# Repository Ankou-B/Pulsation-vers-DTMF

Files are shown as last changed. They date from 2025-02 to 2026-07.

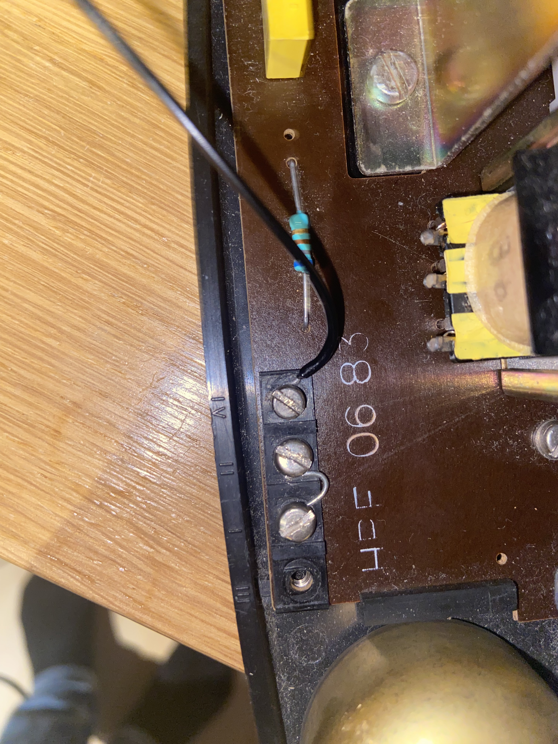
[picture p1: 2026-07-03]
Photos/Vieille photo manuelle/IMG_0554.jpg

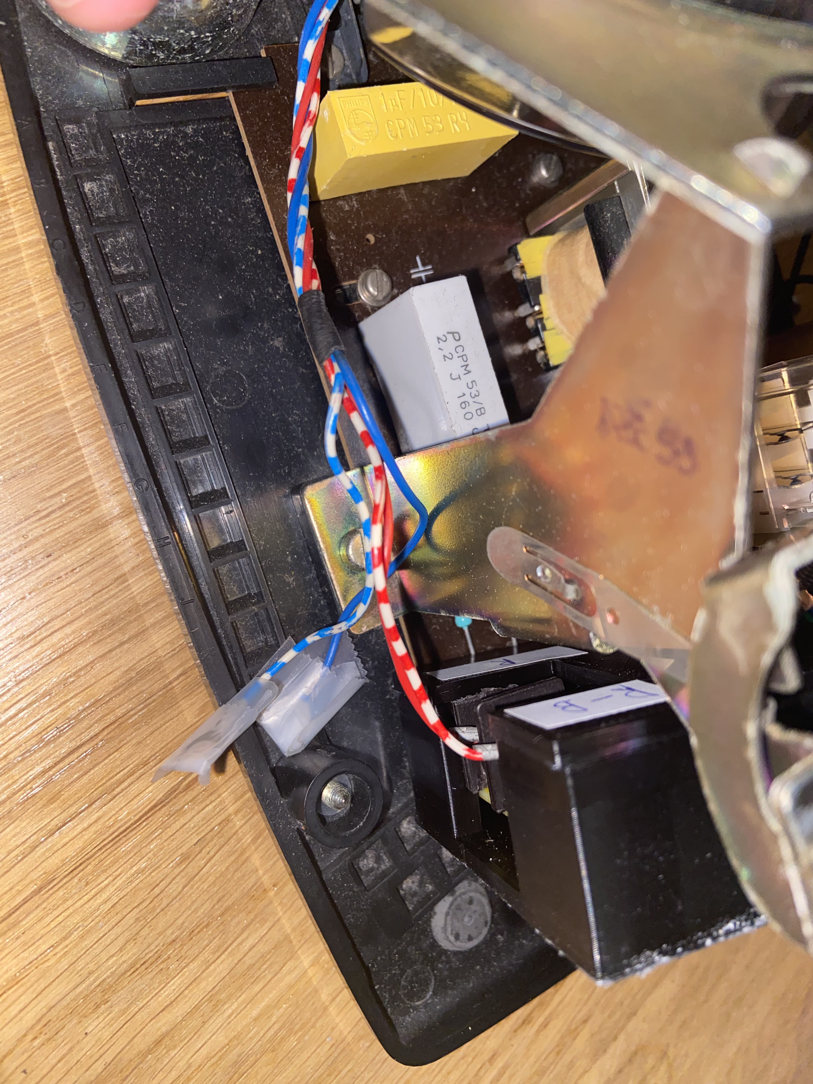
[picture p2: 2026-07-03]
Photos/Vieille photo manuelle/IMG_0558.jpg

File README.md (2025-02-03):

## 🇫🇷 Français

# Pulsation vers DTMF

Ce projet a pour but de faire revivre de vieux téléphones à cadran en leur permettant de composer des numéros à nouveau, malgré l'arrêt des lignes analogiques. 

## 🇺🇸🇬🇧 English

# Pulse to DTMF

This project aims to bring old rotary phones back to life by allowing them to dial numbers again, despite the shutdown of analog lines.

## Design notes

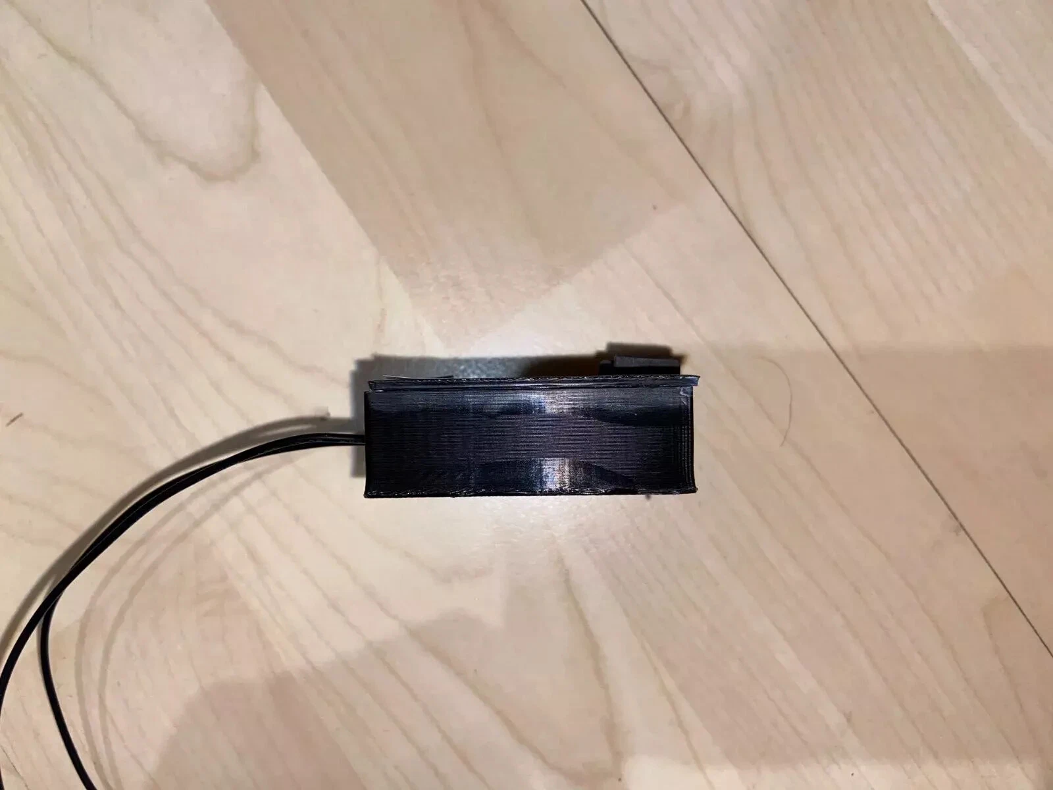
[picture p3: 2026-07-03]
Photos/Vieille photo convertisseur/3/s-l1600 (6).webp

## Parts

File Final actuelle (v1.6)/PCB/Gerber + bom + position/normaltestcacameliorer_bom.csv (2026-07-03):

Designator | Footprint | Quantity | Value | LCSC Part #
 | 7f5ab76e-00c1-41d5-9dfb-255ff1bbb225 | 1
100NF_CONDENSATEUR_CERAMIQUE_1206_1, 100NF_CONDENSATEUR_CERAMIQUE_1206_2 | 1206 | 2 | 100nf Ceramic Capacitor 1206 | C1945
10K_RESITANCE_0603_2 | 0603 | 1 | 10k resistor 0603 | C2930027
20K_RESISTANCE | 0603 | 1 | 20k 0603 | C2907124
BORNIER_A_VIS_GROS | YK3310203000G | 1 | P=8.25mm Barrier Blocks RoHS | C49023053
BORNIER_BLEU | TerminalBlock_MaiXu_MX126-5.0-02P_1x02_P5.00mm | 1 | KF301-5.0-2P | C474881
CONDENSATEUR_CHIMIQUE | C_Elec_5x5.8 | 1 | 50V10UF | C2992603
MICROCONTRÔLEUR | SOIC8-N_MC_MCH-M | 1 | PMS150C | C129127
PONT_REDRESSEUR | TO-269AA_3P8X4P75_DIO-M | 1 | MB10S | C2886577
QUARTZ | QUARTZ | 1 | 3.579545 HC-49S | C20617532
RESISTANCE_12K_0603 | 0603 | 1 | 12k resistor 0603 | C2907097
RESISTANCE_1K_0603_1, RESISTANCE_1K_0603_2 | 0603 | 2 | 1k resistor 0603 | C2907113
TP5088N | DIL-14 | 1
TRANSISTOR_NPN | SOT-23_DIO | 1 | MMBT2222A | C916372
Z5.1V | D_DO-41_SOD81_P10.16mm_Horizontal | 1 | 1N4733A 1W 5.1V D_DO-41_SOD81_P10.16mm_Horizontal | C7441079

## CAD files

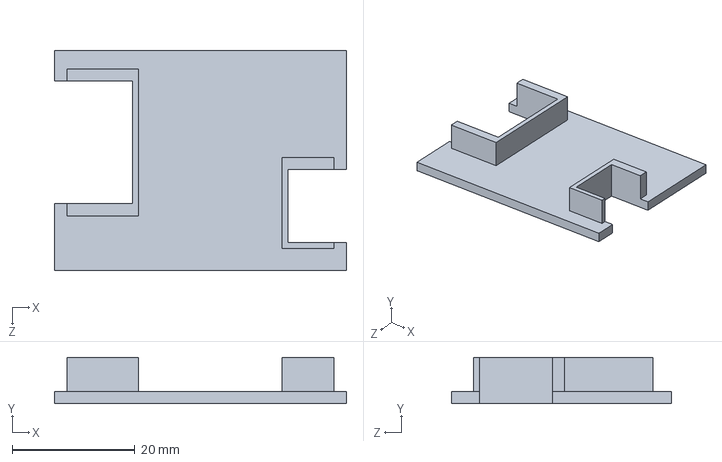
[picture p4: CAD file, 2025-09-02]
Avant le site (v1.5)/3D/Coque LiperPhone v1.5/Haut LiperPhone v1.5.SLDPRT
47.5 x 7.50 x 35.8 mm

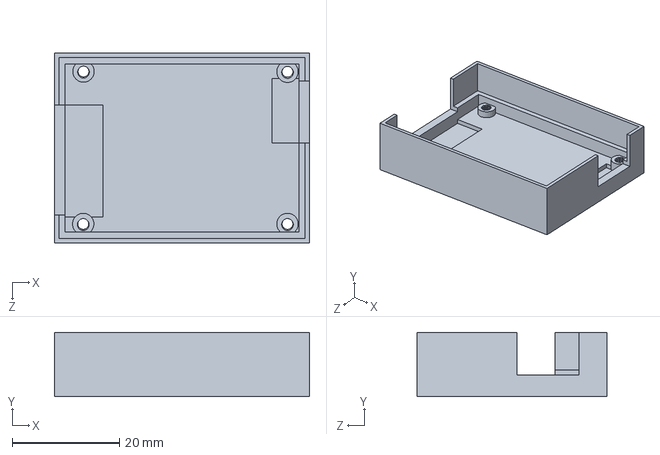
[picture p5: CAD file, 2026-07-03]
Final actuelle (v1.6)/3D/Bas LiperPhone v1.6.SLDPRT
47.5 x 12.0 x 35.3 mm

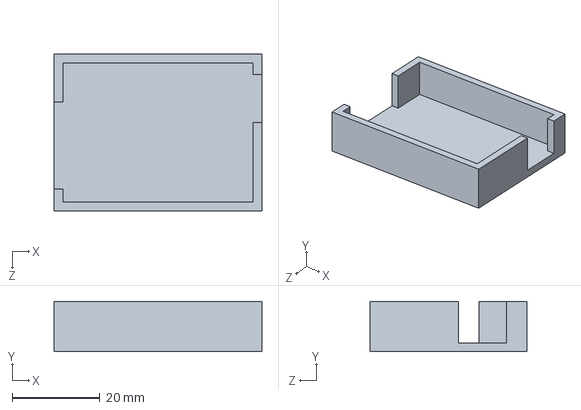
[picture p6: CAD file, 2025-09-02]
Avant le site (v1.5)/3D/Coque LiperPhone v1.5/Bas LiperPhone v1.5.SLDPRT
47.5 x 11.5 x 35.8 mm

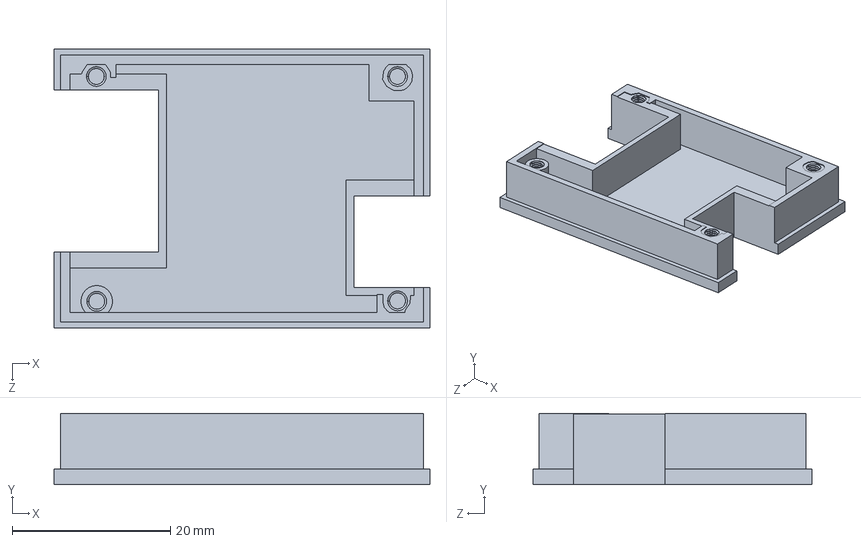
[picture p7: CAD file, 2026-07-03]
Final actuelle (v1.6)/3D/Haut LiperPhone v1.6.SLDPRT
47.5 x 9.00 x 35.3 mm

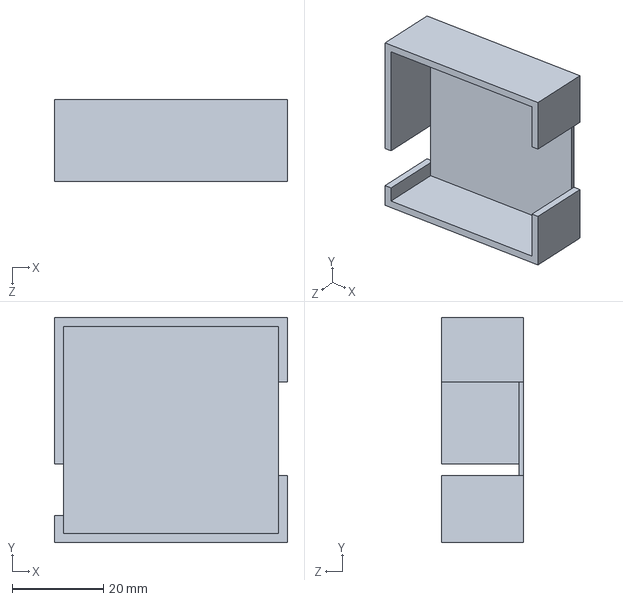
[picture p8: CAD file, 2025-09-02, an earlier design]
Ancien final (v1.2)/3D/coque LiperPhone/Aelig 1 (3).SLDPRT
51.2 x 49.5 x 18.0 mm

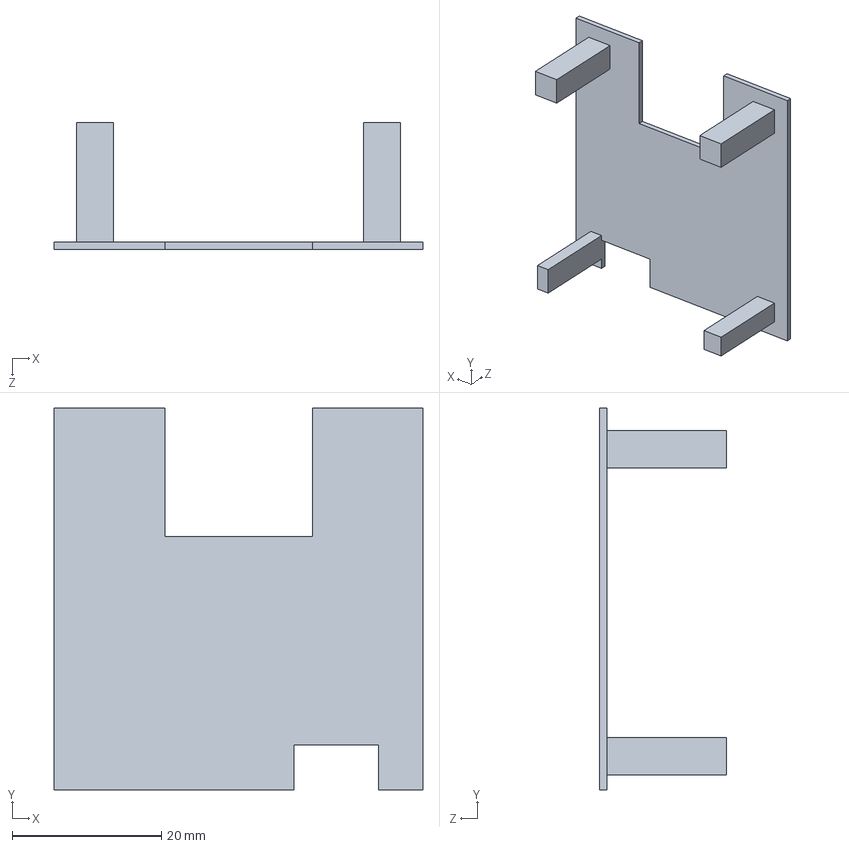
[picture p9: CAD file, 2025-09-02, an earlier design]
Ancien final (v1.2)/3D/coque LiperPhone/Aelig 2 (1).SLDPRT
49.5 x 51.2 x 17.0 mm

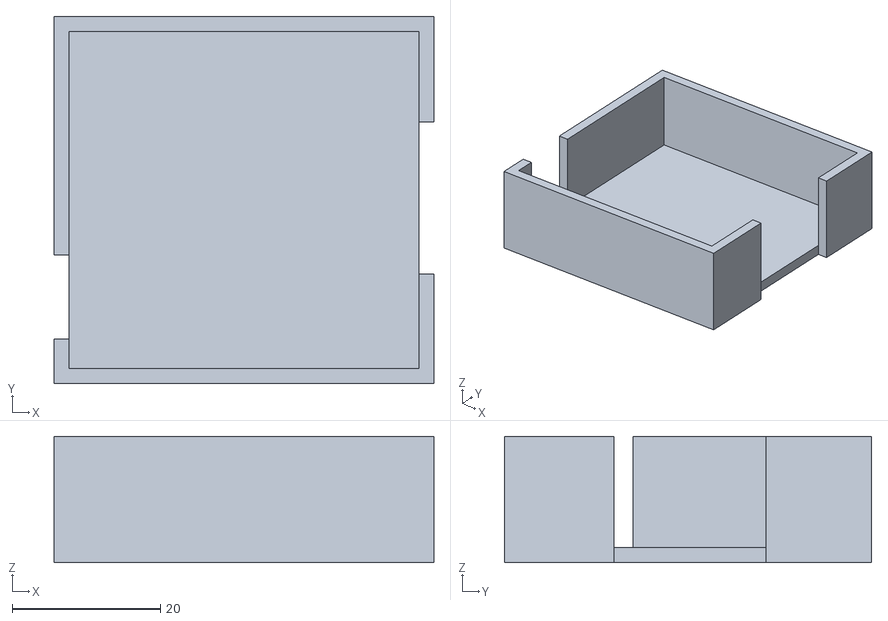
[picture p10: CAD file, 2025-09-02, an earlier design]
Ancien final (v1.2)/3D/coque LiperPhone/Liperphone bas v1.STL
51.2 x 49.5 x 17.0

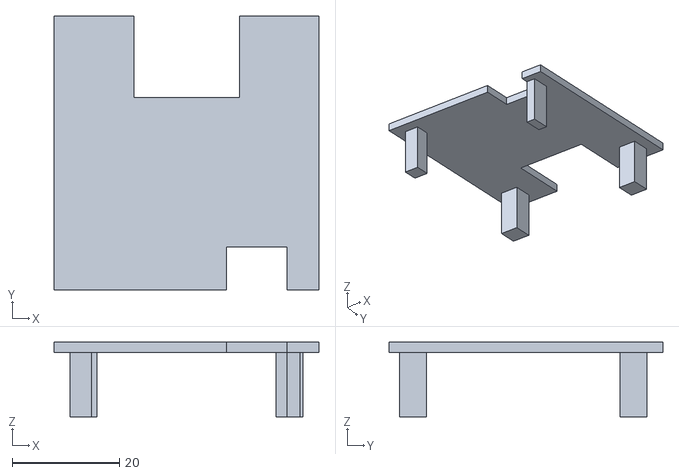
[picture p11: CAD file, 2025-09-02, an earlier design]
Ancien final (v1.2)/3D/coque LiperPhone/Liperphone haut v1.STL
49.5 x 51.2 x 14.0

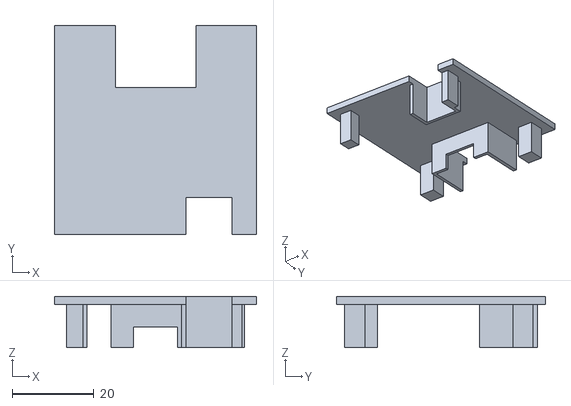
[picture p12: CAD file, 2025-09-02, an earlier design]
Ancien final (v1.2)/3D/coque LiperPhone/Liperphone haut v3.STL
49.5 x 51.2 x 12.5

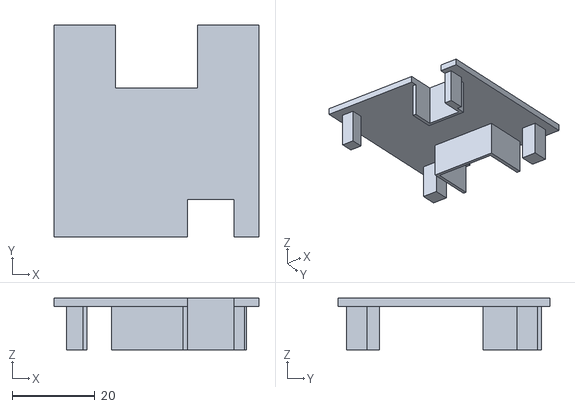
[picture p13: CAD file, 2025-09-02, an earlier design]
Ancien final (v1.2)/3D/coque LiperPhone/Liperphone haut v2.STL
49.5 x 51.2 x 12.5

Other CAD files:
Ancien final (v1.2)/3D/coque LiperPhone/Aelig 1 1mm.STL
Ancien final (v1.2)/3D/coque LiperPhone/Aelig 2 1mm.STL
Avant le site (v1.5)/3D/Coque LiperPhone v1.5/Bas LiperPhone v1.5.STL
Avant le site (v1.5)/3D/Coque LiperPhone v1.5/Haut LiperPhone v1.5.STL
Final actuelle (v1.6)/3D/Bas LiperPhone v1.6.STL
Final actuelle (v1.6)/3D/Haut LiperPhone v1.6.STL

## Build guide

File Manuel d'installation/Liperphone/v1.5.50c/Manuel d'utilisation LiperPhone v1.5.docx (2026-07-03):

Manuel d’utilisation - LiperPhone v1.5

Les instructions sont simples et peu nombreuses : la lecture de ce document sera rapide, rassurez-vous !

À éviter absolument :
Ne tournez pas le cadran trop violemment ni par à-coups. Il s’agit d’un matériel d’époque, qui devient un peu plus fragile avec le temps, et qui mérite donc d’être manipulé avec soin. Un usage brutal pourrait non seulement l’endommager, mais aussi provoquer des erreurs de numérotation avec le LiperPhone, ce que nous voulons éviter, évidemment.

Utilisation du cadran
Une fois arrivé à la butée avec le chiffre désiré, relâchez simplement le cadran et laissez-le revenir tranquillement à sa position initiale. Vous entendrez un son dans l’écouteur, signe que tout s’est bien déroulé. Il est important de ne pas accélérer ni freiner le retour du cadran : cela risquerait de provoquer une erreur de numérotation du LiperPhone.

Composer un chiffre est donc très simple : amenez le chiffre voulu jusqu’à la butée, puis relâchez immédiatement le cadran.

Important : attendez que la tonalité du chiffre en cours soit terminée (≈ ¼ de seconde) avant de commencer le chiffre suivant. Si vous enchaînez trop vite, votre box peut mal interpréter la numérotation.

Numérotation — cadence et cas particuliers

Si, lors de l’amener à la butée, la rotation est très lente ou hésitante, le convertisseur peut générer un chiffre parasite (brève tonalité entendue dans l’écouteur).
Dans ce cas :

- Raccrochez au moins 5 secondes,
- puis recommencez votre numéro depuis le début en effectuant des mouvements francs et réguliers.

Caractères spéciaux

- Pour composer un *, amenez le chiffre 1 jusqu’à la butée, attendez 2 secondes, puis relâchez le cadran. Le LiperPhone générera alors un * au lieu d’un 1.
- Pour composer une #, procédez de la même manière avec le chiffre 2.
- Pou composer le caractère d’appel internationale +, procédez de la même manière avec le chiffre 3. Information complémentaire, vous entendrez deux tonalités qui se suivent, c’est normal.

Comme vous pouvez le constater, il n’y a pas grand-chose à lire : le fonctionnement d’un téléphone à cadran reste simple et intuitif.

Dépannage rapide

- Rien ne se passe après un raccrochage/décrochage très rapide, ou une tonalité continue se déclenche : raccrochez 5 secondes, puis recommencez la numérotation depuis le début.
- Chiffre inattendu entendu pendant la rotation : cadence irrégulière → appliquez la procédure ci-dessus (raccrocher 5 s puis recommencer).

Liper

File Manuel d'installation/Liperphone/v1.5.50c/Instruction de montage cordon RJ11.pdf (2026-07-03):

Instruction d’installation cordon RJ11

Merci pour votre achat !

Si vous avez un problème avec les instructions, n’hésitez pas à m’envoyer un message sur la plateforme où vous avez acheté le produit. (Mais lisez et appliquez bien toutes les instructions avant).

Vous trouverez ci-dessous les instructions d’installation du cordon RJ11.

Pour le modèle S63

1ʳᵉ étape : Ouvrir le téléphone à cadran

Pour ouvrir le téléphone à cadran, rien de plus simple : sous celui-ci, il y a deux vis. Il suffit de les dévisser complètement toutes les deux, et la coque devrait se retirer sans forcer.

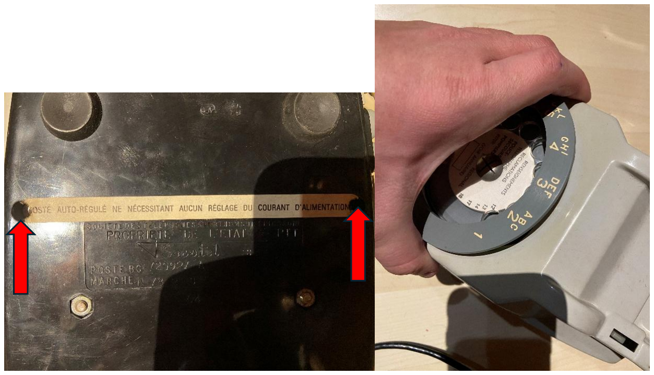
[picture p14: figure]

Un exemple vidéo si besoin :
(2:29 – 2:54) https://www.youtube.com/watch?v=tPKWj8iQFak

2ᵉ étape : Retirer les fils de l’ancienne prise

Les fils à débrancher se situent ici sur le téléphone. Dévissez tranquillement pour ne pas retirer la vis complètement.

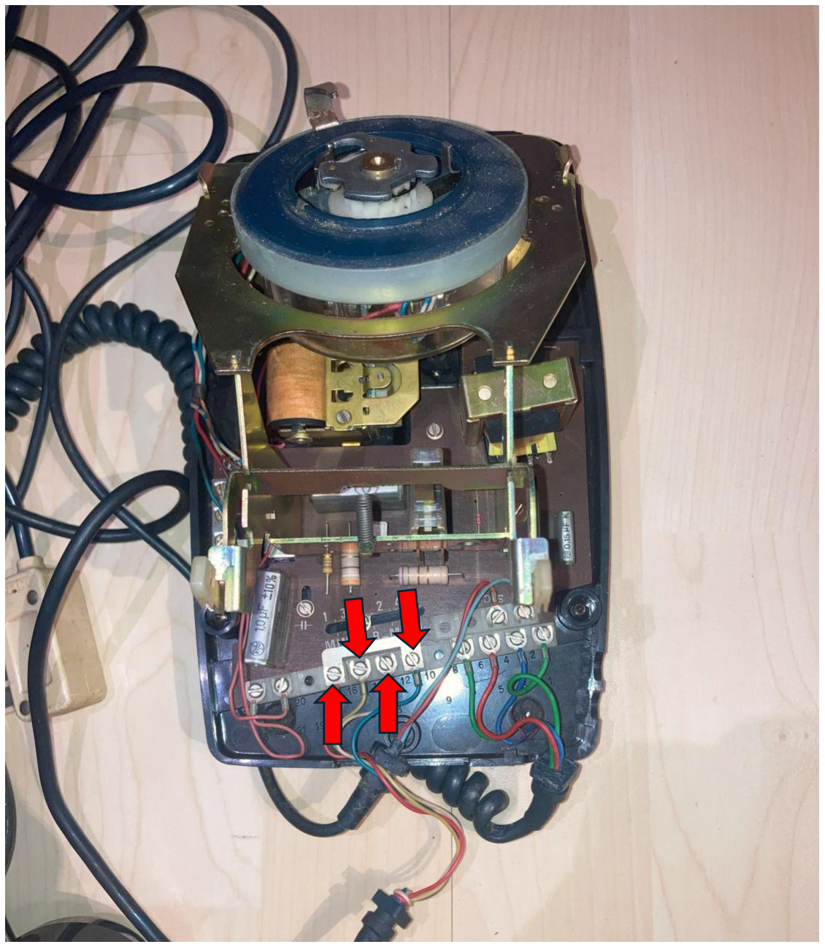
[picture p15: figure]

Il ne faut pas retirer les vis, juste déloger les câbles. Veillez à laisser le petit pont en métal bien en place.

3ᵉ étape : Visser les fils de la nouvelle prise

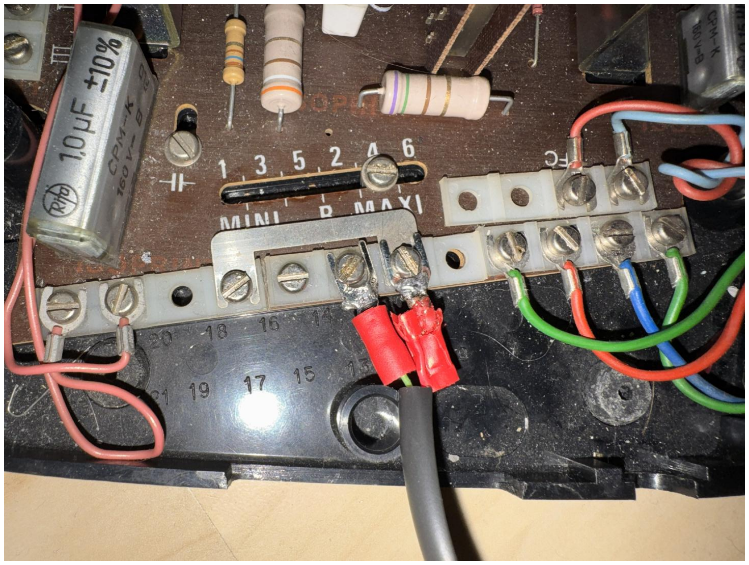
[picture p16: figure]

Le sens des fils n’a pas d’importance : les deux fils sont interchangeables et peuvent aller sur n’importe laquelle des deux bornes de la photo.
Vissez fermement pour que les cosses ne puissent pas bouger.
Revissez aussi les vis sans cosses et portez une attention particulière à celle avec le petit pont de métal : elle doit être très bien serrée pour que le contact se fasse correctement.

4ᵉ étape : Vérification

Avant de refermer, n’hésitez pas à brancher votre téléphone à votre ligne (box ADSL/fibre, prise murale, etc.) et à essayer de vous appeler. Cela vous permettra de vérifier si le signal arrive correctement au téléphone.

5ᵉ étape : Refermez, c’est terminé

Quand vous refermez, vérifiez bien qu’aucun câble ne dépasse de la coque du téléphone et revissez correctement les vis de ladite coque.
Faites en sorte que le petit embout soit installé comme ceci lors de la fermeture, quitte à devoir pousser un peu le câble à l’intérieur pour y parvenir.

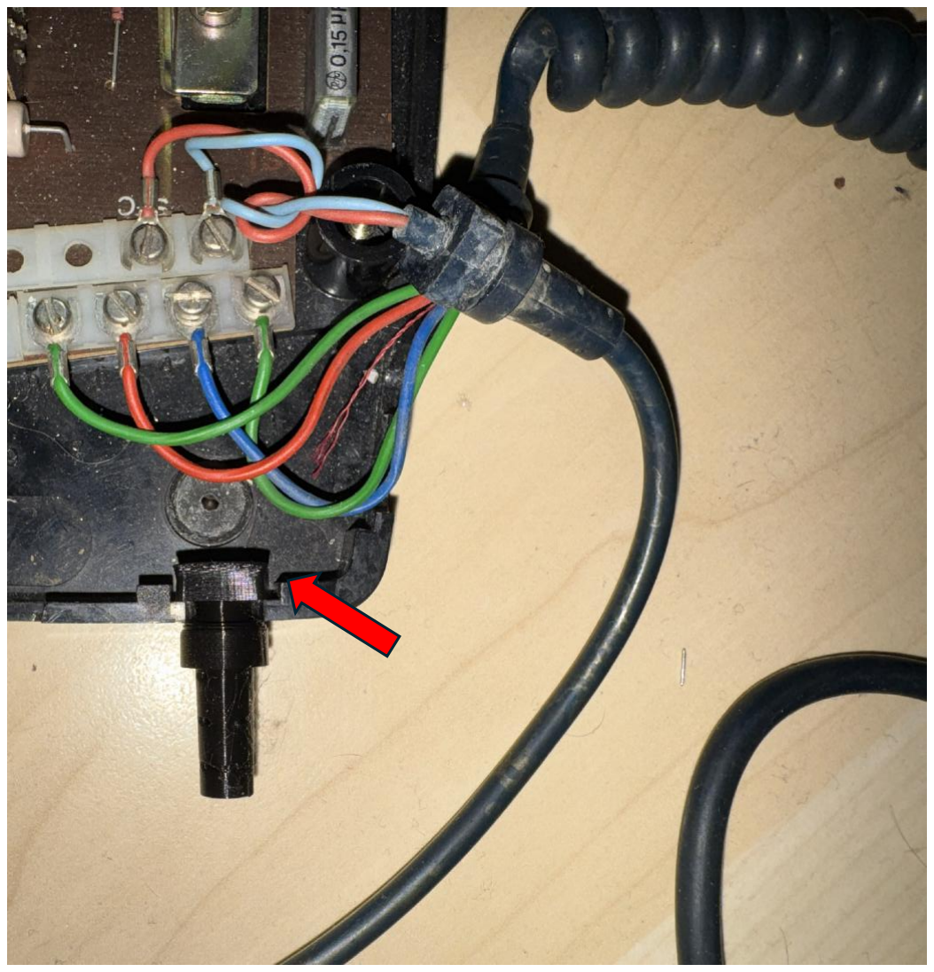
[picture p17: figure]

Et voilà !

# Liper

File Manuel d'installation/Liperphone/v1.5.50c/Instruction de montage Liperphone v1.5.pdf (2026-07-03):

Instruction de montage Liperphone v1.5

Merci pour votre achat !

Si vous avez un problème avec les instructions, n’hésitez pas à m’envoyer un message sur la plateforme où vous avez acheté le Liperphone. (Mais lisez et appliquez bien toutes les instructions avant).

Vous trouverez ci-dessous les instructions d’installation du Liperphone v1.5.

Pour le modèle S63

1ʳᵉ étape : Ouvrir le téléphone à cadran

Pour ouvrir le téléphone à cadran, rien de plus simple : sous celui-ci, il y a deux vis. Il suffit de les dévisser complètement toutes les deux, et la coque devrait se retirer sans forcer.


Un exemple vidéo :
(2:29 – 2:54) https://www.youtube.com/watch?v=tPKWj8iQFak

2ᵉ étape : Débrancher le cadran
Afin de pouvoir brancher les fils du cadran sur le Liperphone, il faut d’abord les débrancher du téléphone.

Les fils à débrancher se situent ici sur le cadran (à noter qu’il peut être à gauche ou à droite selon le téléphone, mais cela ne change rien à la procédure).

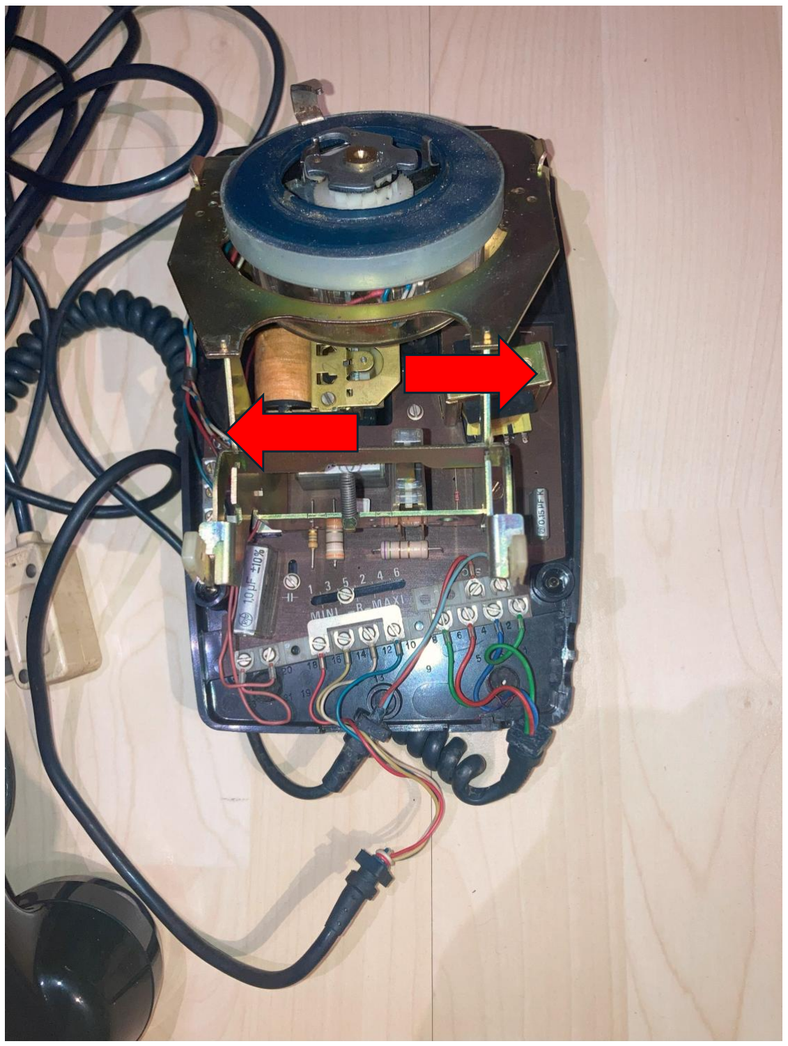
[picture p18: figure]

(La flèche ne pointant rien est juste là pour préciser l’emplacement sur certains téléphones.)

Il faut donc essayer de retenir dans quel sens sont branchés les câbles.
Ou bien, une majorité de ces téléphones ont un chiffre romain près des borniers retenant les fils du cadran, comme on peut le voir sur cette photo, directement sur la carte du téléphone.

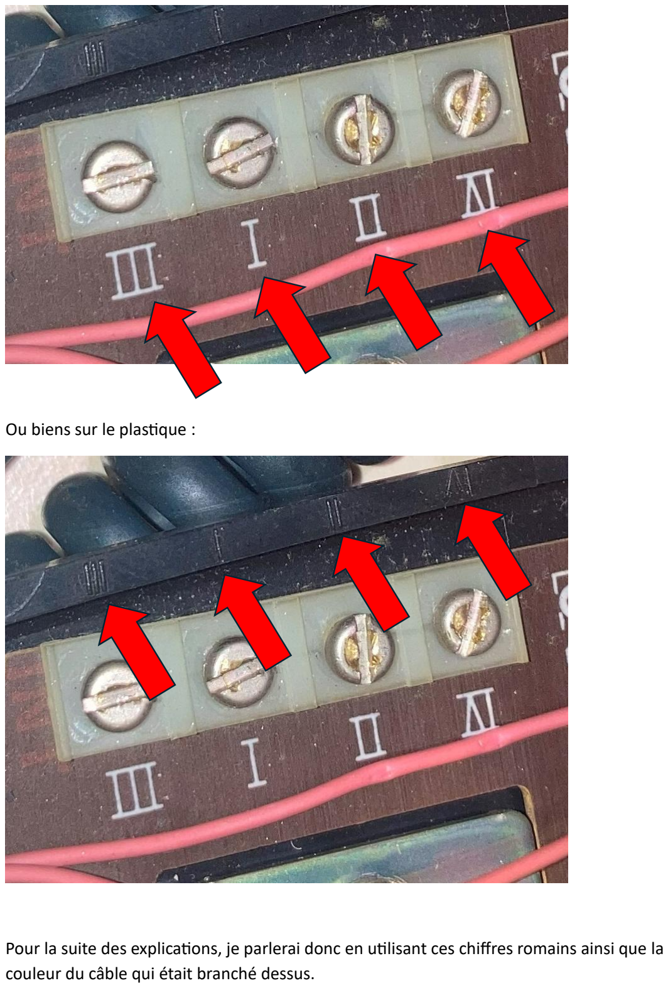
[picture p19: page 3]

Ou biens sur le plastique :

Pour la suite des explications, je parlerai donc en utilisant ces chiffres romains ainsi que la couleur du câble qui était branché dessus.

3ᵉ étape : Isoler le câble bleu et le câble rouge-blanc que vous venez de déconnecter

Pour les isoler, vous pouvez entièrement les couper, mais je ne le conseille pas vraiment, car cela pourrait abîmer l’intérieur de votre téléphone. Vous pouvez simplement entourer l’embout de ruban adhésif afin qu’ils ne puissent plus entrer en contact malencontreusement.

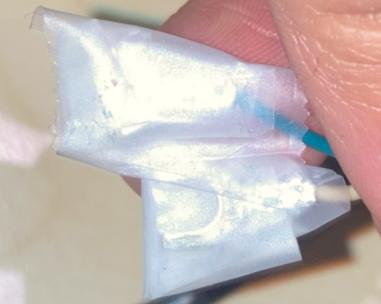
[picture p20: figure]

4ᵉ étape : Relier le port I et le port II

Tout à l’heure, nous avons débranché les fils du cadran. Il faut maintenant relier les ports I et II. Pour se faire, relier les deux fils sortant du convertisseur, l’un sur le port I et l’autre sur le port II. L’ordre n’a pas d’importance. Coincez le bout du câble sous la vis, puis serrez fermement pour que le contact se fasse bien et que le câble ne puisse pas se déplacer. Vérifiez que le câble est bien en dessous de la vis après avoir serré, car il a tendance à se déplacer pendant le vissage et à ne plus être bien installé.

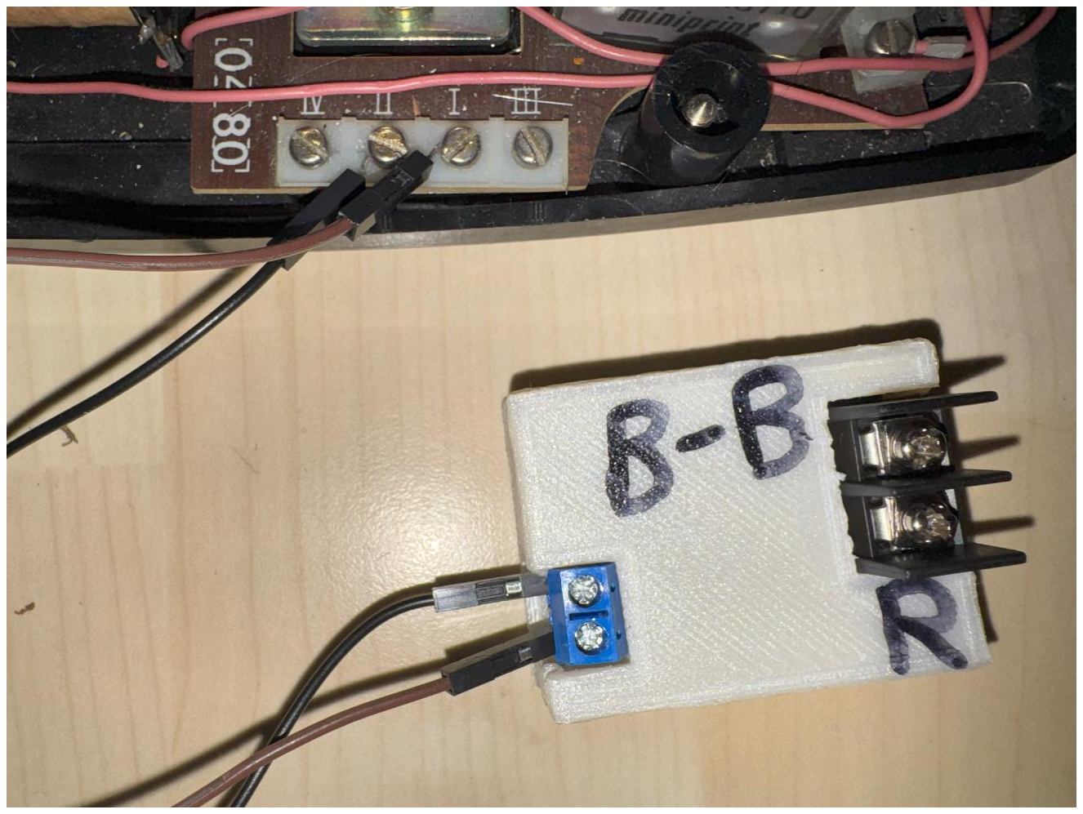
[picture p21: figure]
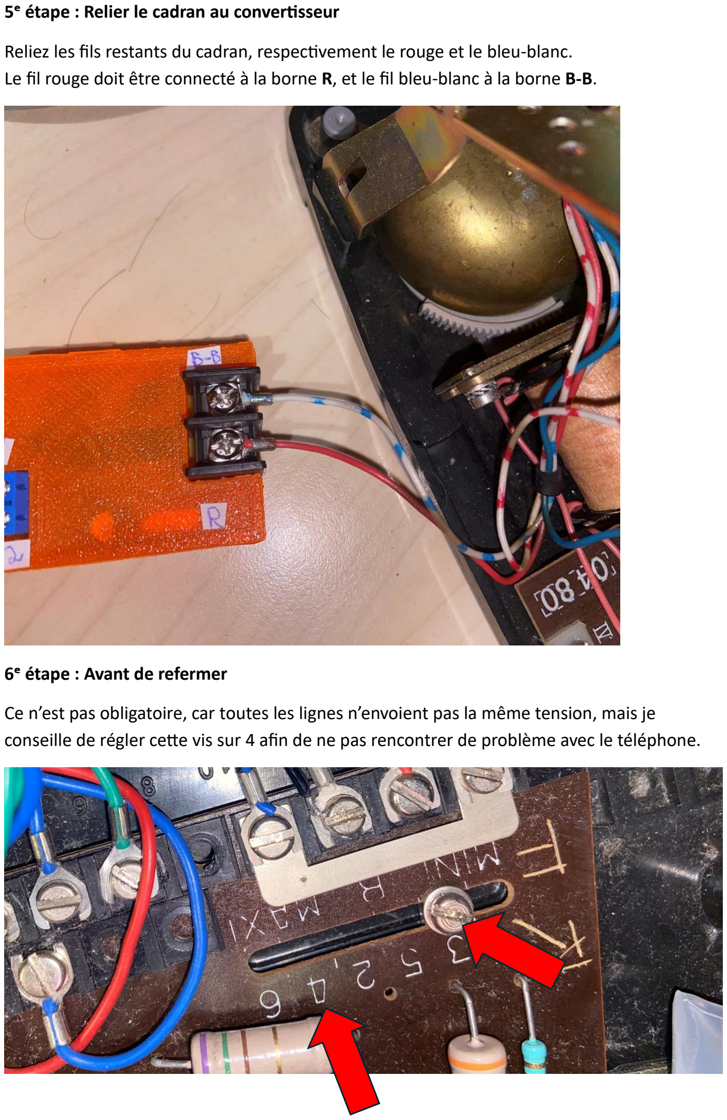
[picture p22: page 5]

5ᵉ étape : Relier le cadran au convertisseur

Reliez les fils restants du cadran, respectivement le rouge et le bleu-blanc. Le fil rouge doit être connecté à la borne R, et le fil bleu-blanc à la borne B-B.

6ᵉ étape : Avant de refermer

Ce n’est pas obligatoire, car toutes les lignes n’envoient pas la même tension, mais je conseille de régler cette vis sur 4 afin de ne pas rencontrer de problème avec le téléphone.

7ᵉ étape : Vérification

Avant de refermer, n’hésitez pas à brancher votre téléphone à votre ligne (box ADSL/fibre, murale, etc.) et essayer de composer un numéro. Cela vous permettra de vérifier si vous entendez bien une tonalité et vous permettra de voir le bon fonctionnement de vos branchements.

8ᵉ étape : Refermez, c’est terminé

Pour bien positionner le convertisseur, je vous conseille de mettre le convertisseur derrière le cadrant. Il peut se mettre un peu partout à la vue de sa petite taille, mais ça reste la position idéale.

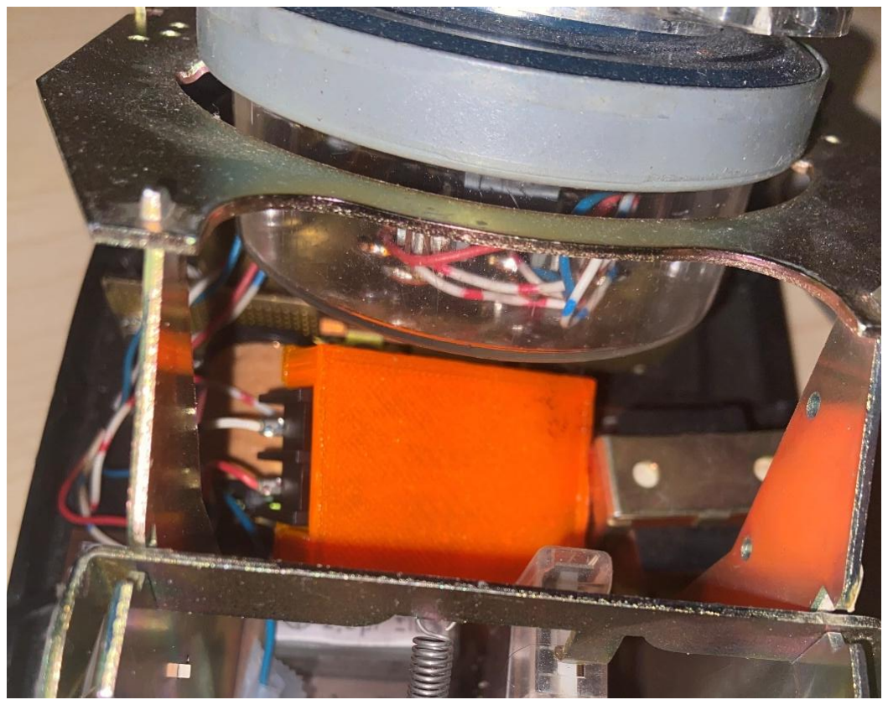
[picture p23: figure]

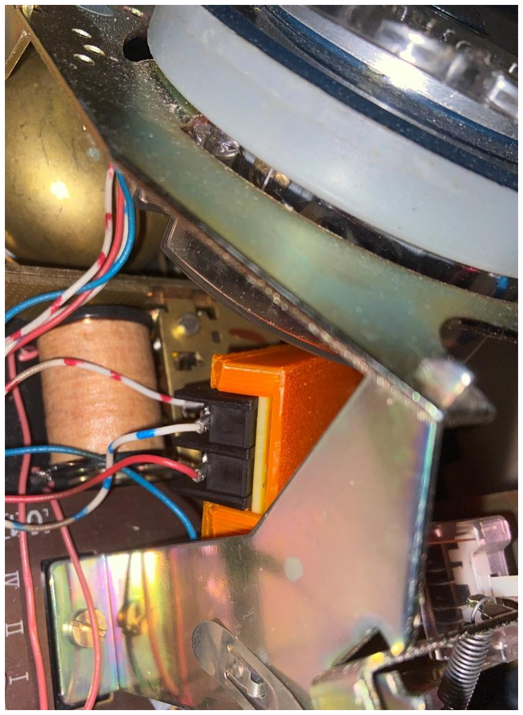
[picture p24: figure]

(Image d’illustration, tous les câbles ne sont pas branchés)

Quand vous refermez, vérifiez bien qu’aucun câble ne dépasse de la coque du téléphone et revissez bien les vis de ladite coque.

Pour le modèle U43

La partie pour le U43 sera un peu plus rapide. Veuillez lire les instructions pour le S63 si celles-ci vous paraissent peu claires, cela devrait vous aider à comprendre.

Je ne peux pas refaire les photos pour le U43, mais il faut bien relier le câble bleu-blanc au convertisseur et pas le rouge-blanc comme sur les photos.

1ʳᵉ étape : Ouvrir le téléphone à cadran

Exemple vidéo (1:46 – 2:55) : https://www.youtube.com/watch?v=NhdKJBoteUY

Pour ouvrir le téléphone à cadran, suivez ces étapes :

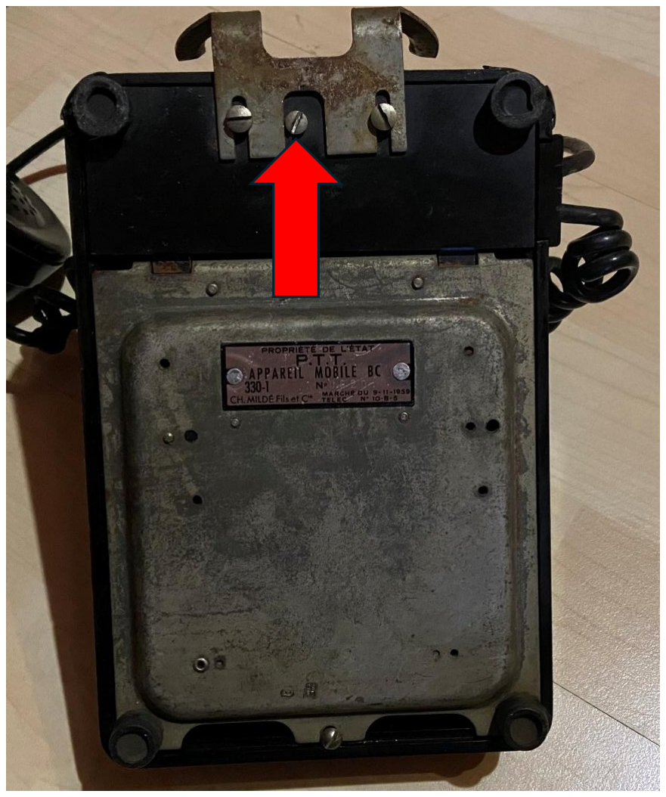
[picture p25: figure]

En premier lieu, dévissez la vis indiquée par une flèche rouge.

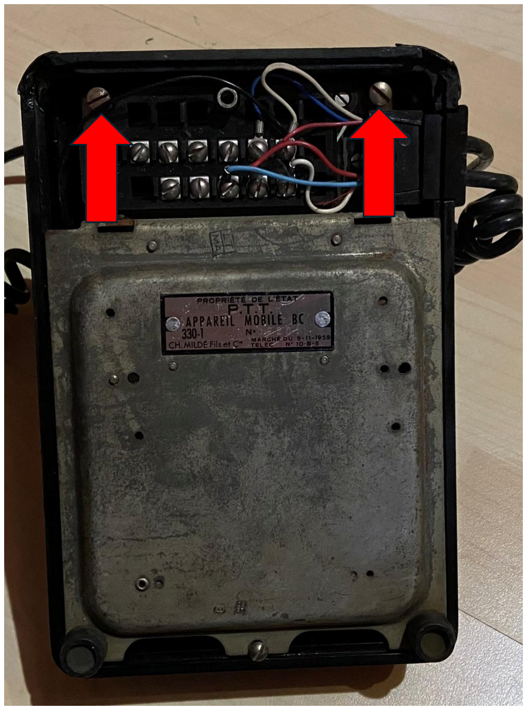
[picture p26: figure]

Une fois cela fait, dévissez les deux grosses vis indiquées par une flèche rouge.

(Je tiens à préciser que mon U43 d'exemple n'est plus en très bon état, mais cela ne change rien.)

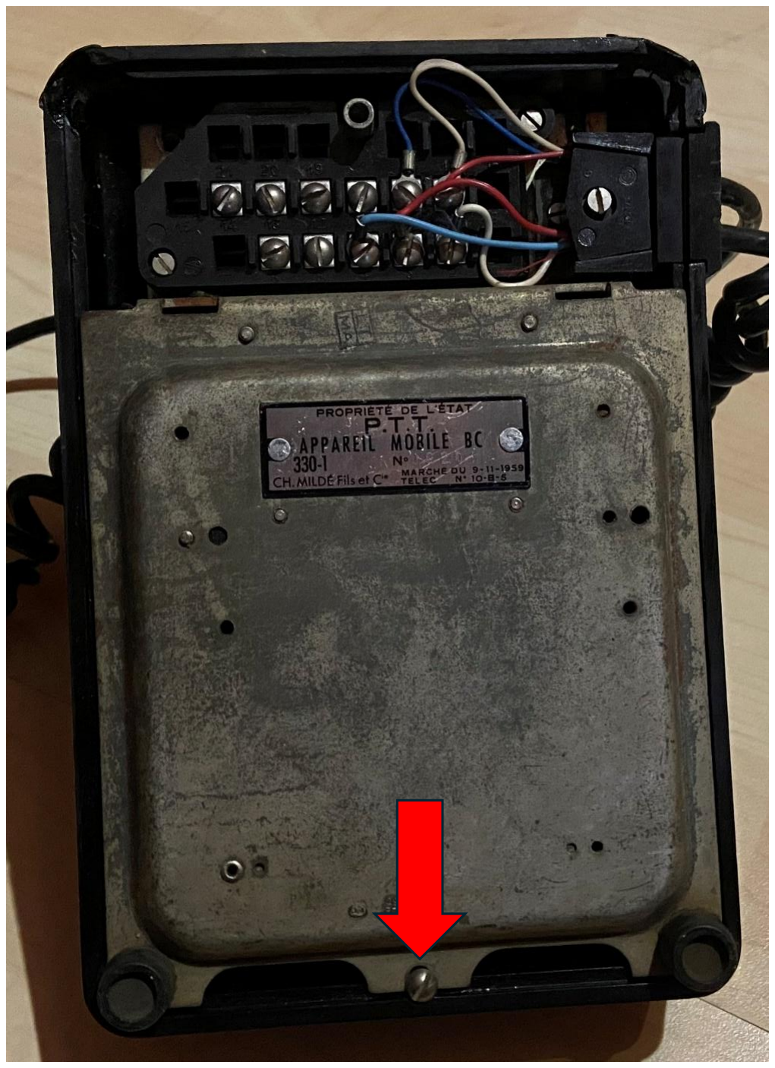
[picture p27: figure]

Il faut encore dévisser cette petite vis située au bout du téléphone, et vous pourrez enfin accéder à l'intérieur.

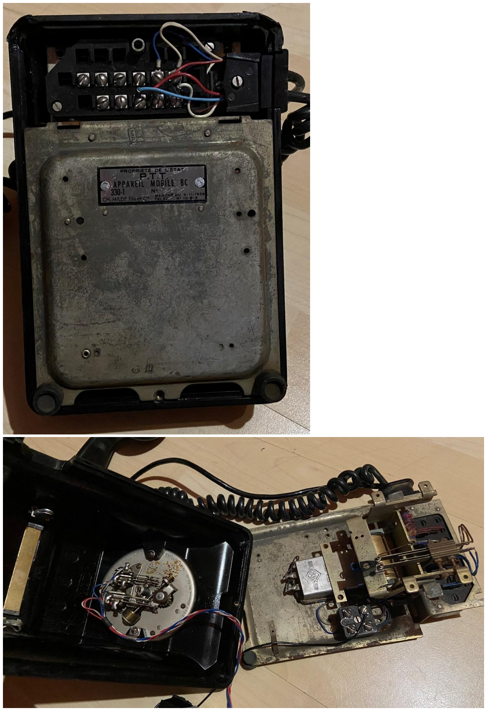
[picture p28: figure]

(Faites comme si les fils n'étaient pas déjà reliés.)

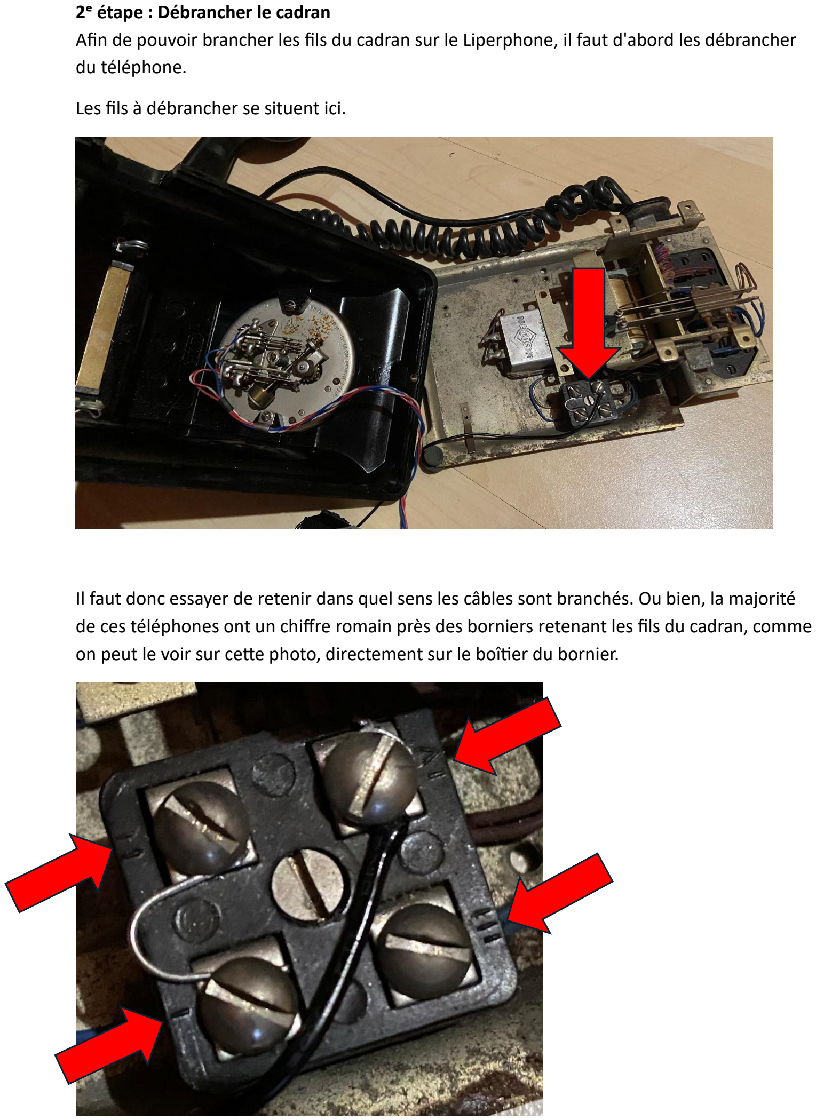
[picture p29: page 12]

2ᵉ étape : Débrancher le cadran
Afin de pouvoir brancher les fils du cadran sur le Liperphone, il faut d'abord les débrancher du téléphone.

Les fils à débrancher se situent ici.

Il faut donc essayer de retenir dans quel sens les câbles sont branchés. Ou bien, la majorité de ces téléphones ont un chiffre romain près des borniers retenant les fils du cadran, comme on peut le voir sur cette photo, directement sur le boîtier du bornier.

3ᵉ étape : Isoler le câble bleu et le câble rouge-blanc que vous venez de déconnecter

Pour les isoler, vous pouvez entièrement les couper, mais je ne le conseille pas vraiment, car cela pourrait abîmer l’intérieur de votre téléphone. Vous pouvez simplement entourer l’embout de ruban adhésif afin qu’ils ne puissent plus entrer en contact malencontreusement.

4ᵉ étape : Relier le port I et le port II

Tout à l’heure, nous avons débranché les fils du cadran. Il faut maintenant relier les ports I et II. Pour se faire, relier les deux fils sortant du convertisseur, l’un sur le port I et l’autre sur le port II. L’ordre n’a pas d’importance. Serrez fermement pour que le contact se fasse bien et que le câble ne puisse pas se déplacer.

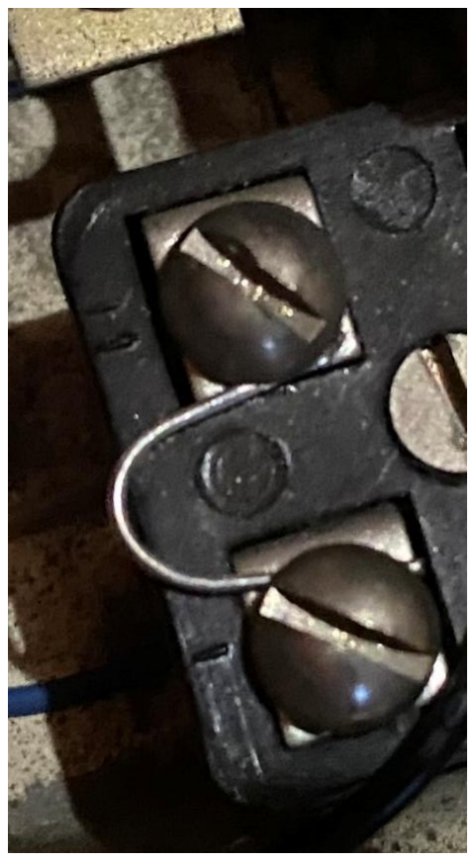
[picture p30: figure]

5ᵉ étape : Relier le cadran au convertisseur

Reliez les fils restants du cadran, respectivement le rouge et le bleu-blanc. Le fil rouge doit être connecté à la borne R, et le fil bleu-blanc à la borne B-B.

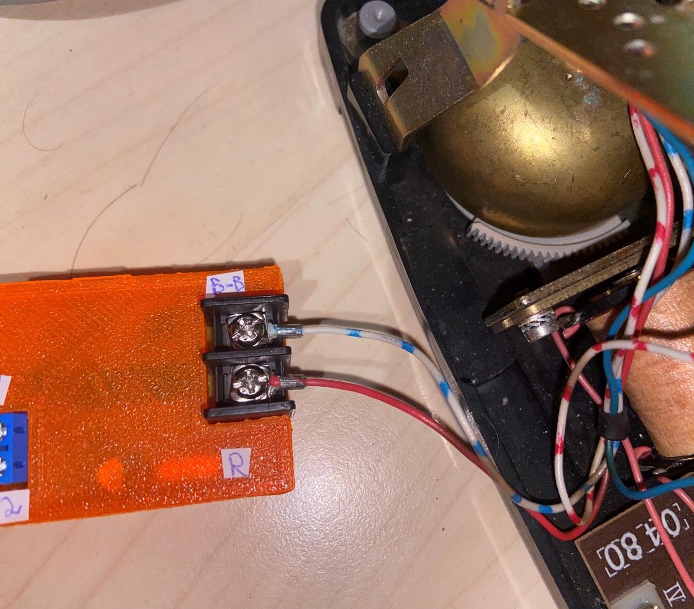
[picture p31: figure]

6

e étape : Placer le convertisseur :

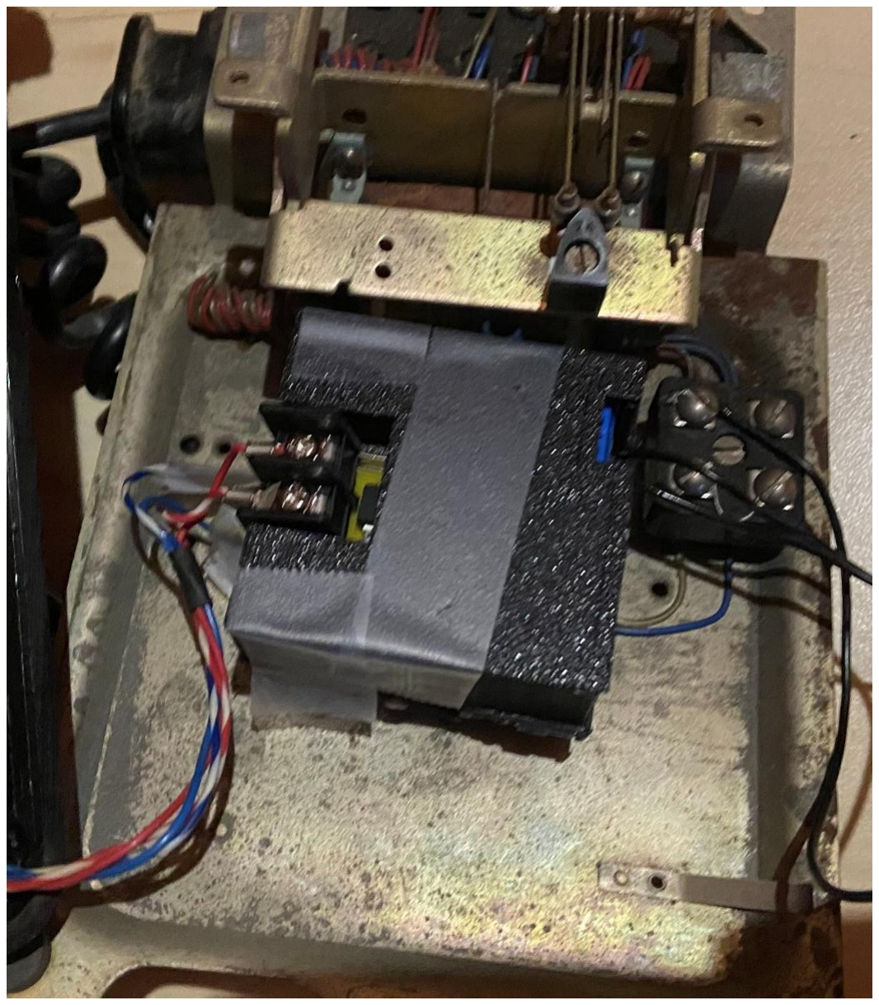
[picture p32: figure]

Si votre téléphone n'est pas équipé d'un ronfleur qui surélèverait le convertisseur, vous pouvez le placer juste ici.

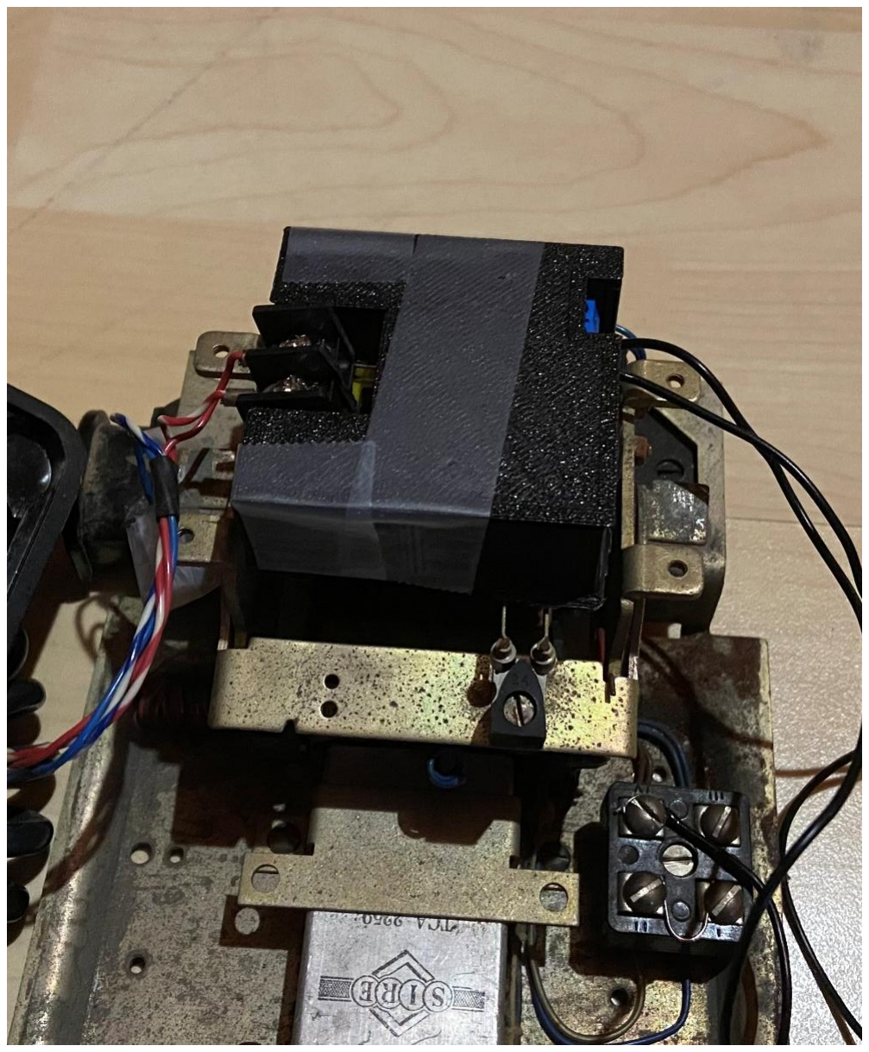
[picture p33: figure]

Autrement, vous pouvez le placer juste ici, mais attention, il faut qu'il soit bien centré, sinon le téléphone ne pourra pas être raccroché.

(Image un peu daté, l’information reste correcte mais la taille étant moins grande qu’avant, il est plus simple de placer correctement le convertisseur)

7ᵉ étape : Vérification

Avant de refermer, n’hésitez pas à brancher votre téléphone à votre ligne (box ADSL/fibre, murale, etc.) et essayer de composer un numéro. Cela vous permettra de vérifier si vous entendez bien une tonalité et vous permettra de voir le bon fonctionnement de vos branchements.

8ᵉ étape : Refermez, c’est terminé

Quand vous refermez, vérifiez bien qu’aucun câble ne dépasse de la coque du téléphone et revissez bien les vis de ladite coque.

Et voilà ! Vous avez un téléphone capable d’appeler à nouveau !

# Liper

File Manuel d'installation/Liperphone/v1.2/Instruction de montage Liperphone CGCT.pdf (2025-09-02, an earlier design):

Reprendre les étapes du Socotel S63.

2

e étape :

Débrancher ces câbles.

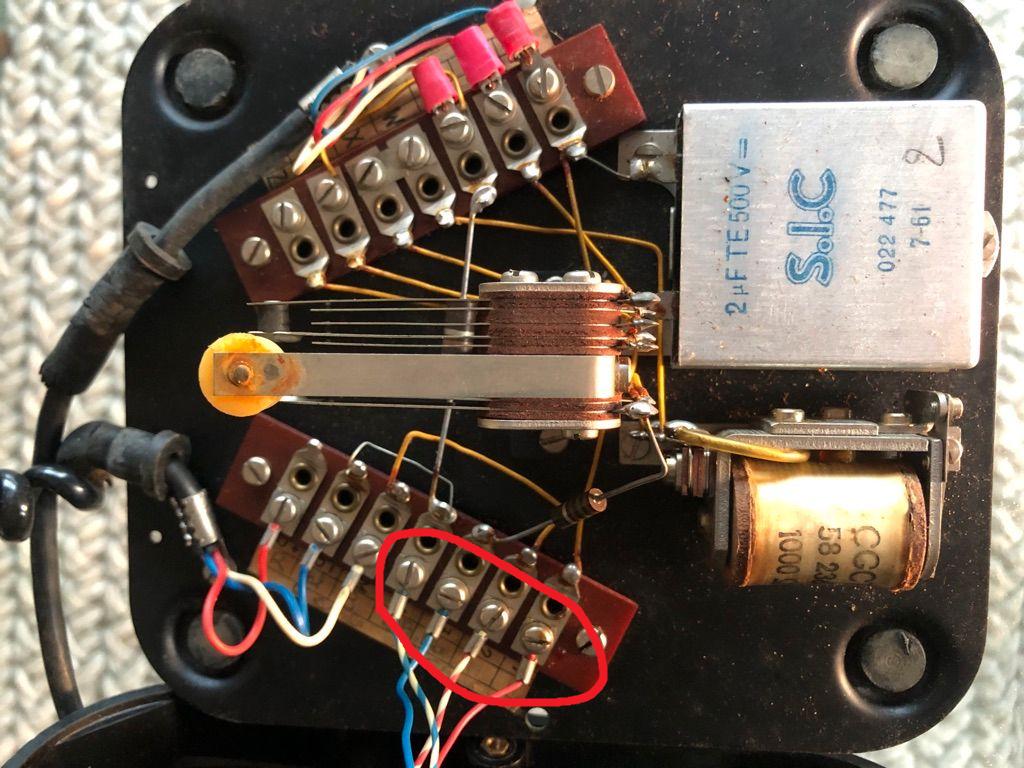
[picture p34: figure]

3

e étape :

Inchangé.

4

e étape :

Relier ces deux ports avec le petit bout de métal.

5

e étape :

Inchangé.

6

e étape :

Faire comme sur les photos pour Socotel S63 à cette endroit.

7ᵉ étape :

Mettre le câble de la borne 2 sous la borne ou était brancher le câble bleu blanc.

Pour le reste suivre les étapes 9 et 10 (pas la 8, il n’y a pas de réglage de puissance dans ce téléphone) en plaçant le convertisseur ou vous pouvez.

# Liper

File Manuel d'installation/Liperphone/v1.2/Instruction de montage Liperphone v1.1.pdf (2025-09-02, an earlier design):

Instruction de montage Liperphone v1.1

Merci pour votre achat !

Si vous avez un problème avec les instructions, n’hésitez pas à m’envoyer un message sur la plateforme où vous avez acheté le Liperphone. (Mais lisez et appliquez bien toutes les instructions avant).

Vous trouverez ci-dessous les instructions d’installation du Liperphone v1.1.

1ʳᵉ étape : Ouvrir le téléphone à cadran

Pour ouvrir le téléphone à cadran, rien de plus simple : sous celui-ci, il y a deux vis. Il suffit de les dévisser complètement toutes les deux, et la coque devrait se retirer sans forcer.

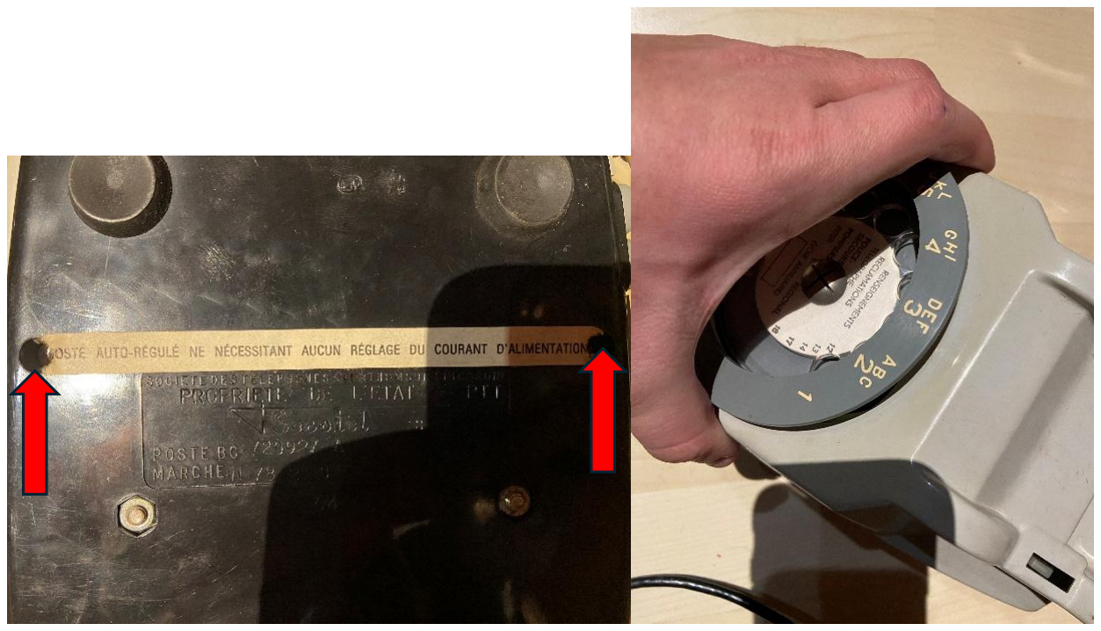
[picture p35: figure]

Un exemple vidéo :
(2:29 – 2:54) https://www.youtube.com/watch?v=tPKWj8iQFak

2ᵉ étape : Débrancher le cadran
Afin de pouvoir brancher les fils du cadran sur le Liperphone, il faut d’abord les débrancher du téléphone.
Les fils à débrancher se situent ici sur le cadran (à noter qu’il peut être à gauche ou à droite selon le téléphone, mais cela ne change rien à la procédure).

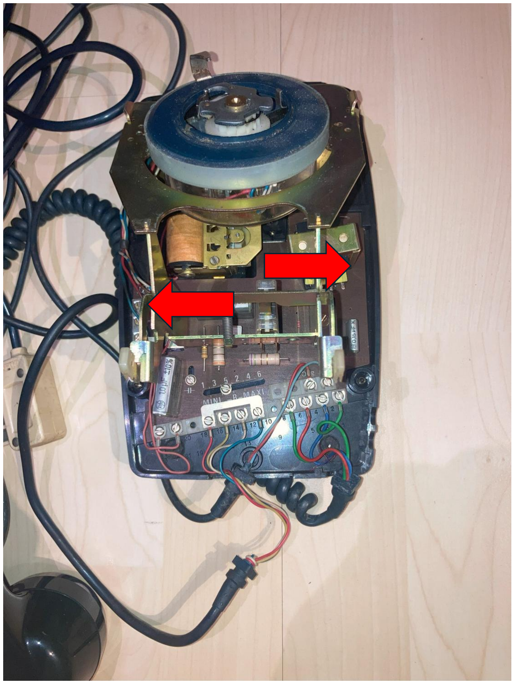
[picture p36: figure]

(La flèche ne pointant rien est juste là pour préciser l’emplacement sur certains téléphones.)

Il faut donc essayer de retenir dans quel sens sont branchés les câbles.
Ou bien, une majorité de ces téléphones ont un chiffre romain près des borniers retenant les fils du cadran, comme on peut le voir sur cette photo, directement sur la carte du téléphone.


Ou biens sur le plastique :

Pour la suite des explications, je parlerai donc en utilisant ces chiffres romains ainsi que la couleur du câble qui était branché dessus.

3ᵉ étape : Isoler le câble bleu et le câble bleu-blanc que vous venez de déconnecter

Pour les isoler, vous pouvez entièrement les couper, mais je ne le conseille pas vraiment, car cela pourrait abîmer l’intérieur de votre téléphone. Vous pouvez simplement entourer l’embout de ruban adhésif afin qu’ils ne puissent plus entrer en contact malencontreusement.


4ᵉ étape : Relier le port I et le port II

Tout à l’heure, nous avons débranché les fils du cadran. Il faut maintenant relier les ports I et II afin d’assurer la continuité du circuit électrique. Vous pouvez les relier avec n’importe quel bout de métal, cela fera l’affaire (j’en mettrai un dans chaque paquet, mais au vu de sa taille, il se peut qu’il se perde). Il suffit simplement de bien coincer le bout de métal sous chacune des deux vis.

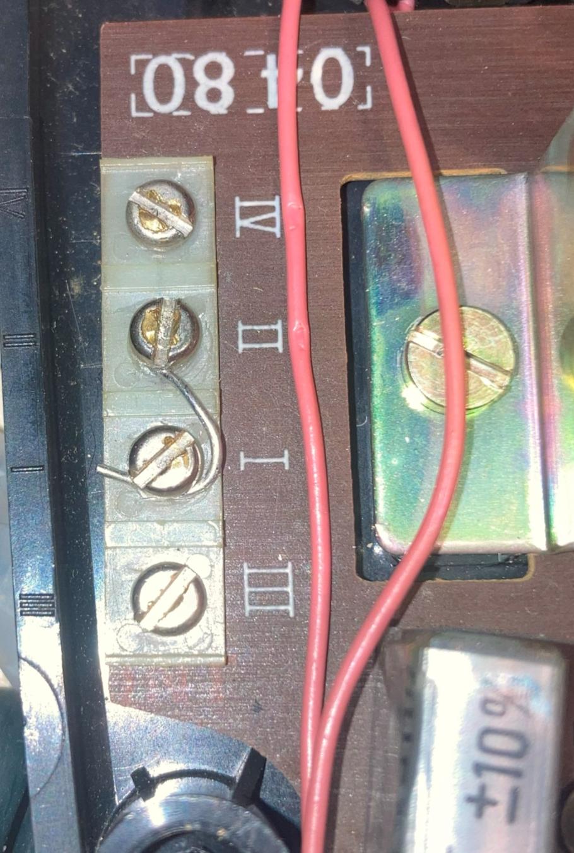
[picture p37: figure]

5ᵉ étape : Relier le cadran au convertisseur

Reliez les fils restants du cadran, respectivement le rouge et le rouge-blanc. Le fil rouge doit être connecté à la borne R, et le fil rouge-blanc à la borne R-B.

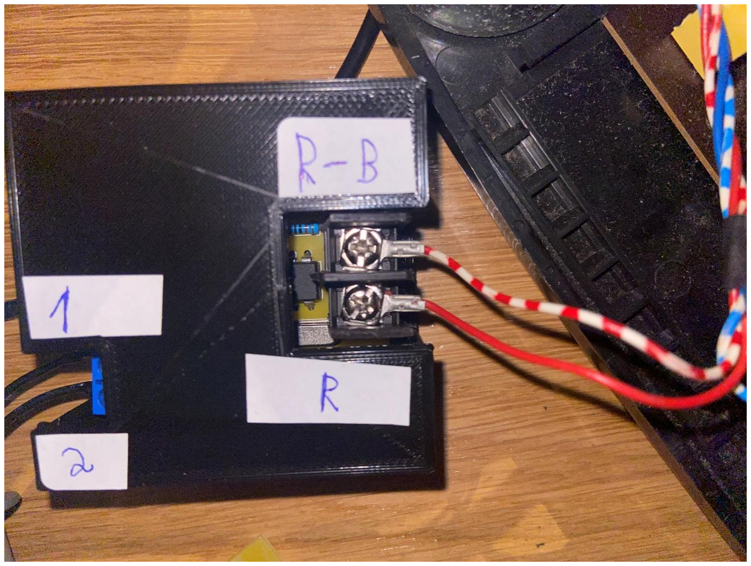
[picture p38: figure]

6ᵉ étape : Relier le câble de la borne 1

Pour relier le câble de la borne 1, il faut tout d’abord repérer le câble blanc à l’arrière du téléphone.

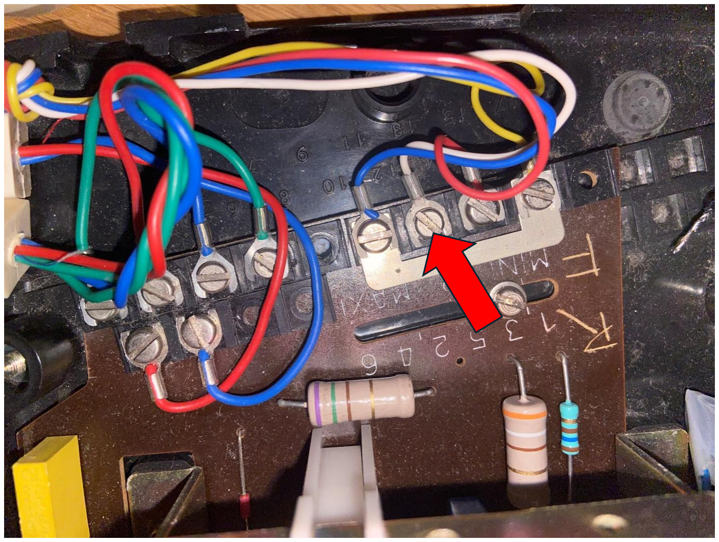
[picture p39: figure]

Une fois trouvé, dévissez la vis de manière à pouvoir glisser le câble sous celle-ci sans retirer la cosse du câble blanc.
Il faut resserrer fermement pour que le contact soit bon (pas besoin de forcer énormément tout de même).

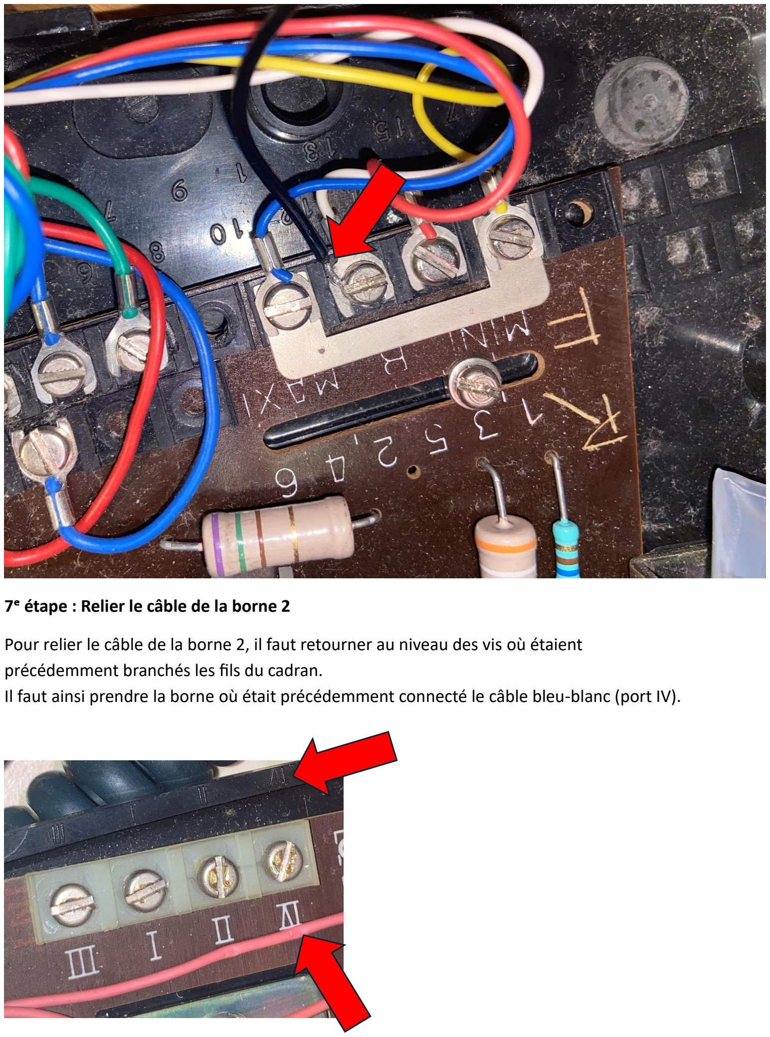
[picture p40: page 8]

7ᵉ étape : Relier le câble de la borne 2

Pour relier le câble de la borne 2, il faut retourner au niveau des vis où étaient précédemment branchés les fils du cadran.
Il faut ainsi prendre la borne où était précédemment connecté le câble bleu-blanc (port IV).

Et coincez le bout du câble sous la vis, puis serrez fermement pour que le contact se fasse bien et que le câble ne puisse pas se déplacer.
Vérifiez que le câble est bien en dessous de la vis après avoir serré, car il a tendance à se déplacer pendant le vissage et à ne plus être bien installé.

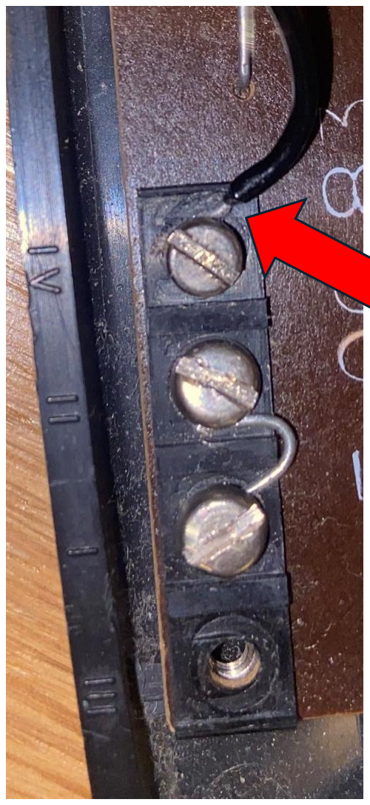
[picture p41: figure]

8ᵉ étape : Avant de refermer

Ce n’est pas obligatoire, car toutes les lignes n’envoient pas la même tension, mais je conseille de régler cette vis sur 4 afin de ne pas rencontrer de problème avec le téléphone.

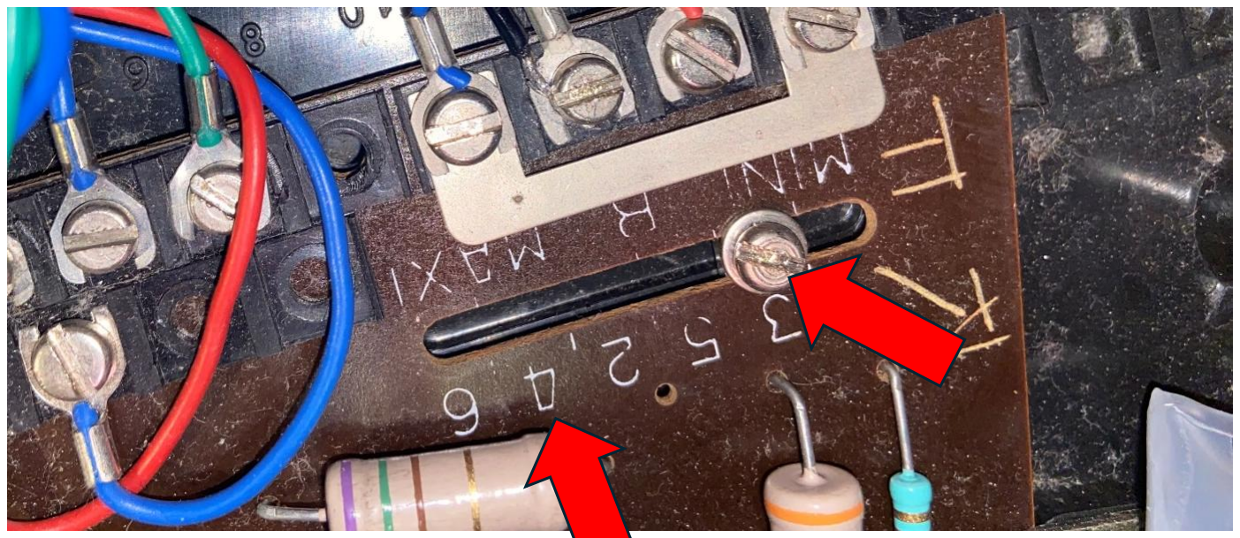
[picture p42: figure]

9ᵉ étape : Vérification

Avant de refermer, n’hésitez pas à brancher votre téléphone à votre ligne (box ADSL/fibre, murale, etc.) et essayer de composer un numéro. Cela vous permettra de vérifier si vous entendez bien une tonalité et vous permettra de voir le bon fonctionnement de vos branchements.

10ᵉ étape : Refermez, c’est terminé

Pour bien positionner le convertisseur et que le téléphone ferme convenablement, je vous conseille cette position : bien droit au centre arrière du téléphone.

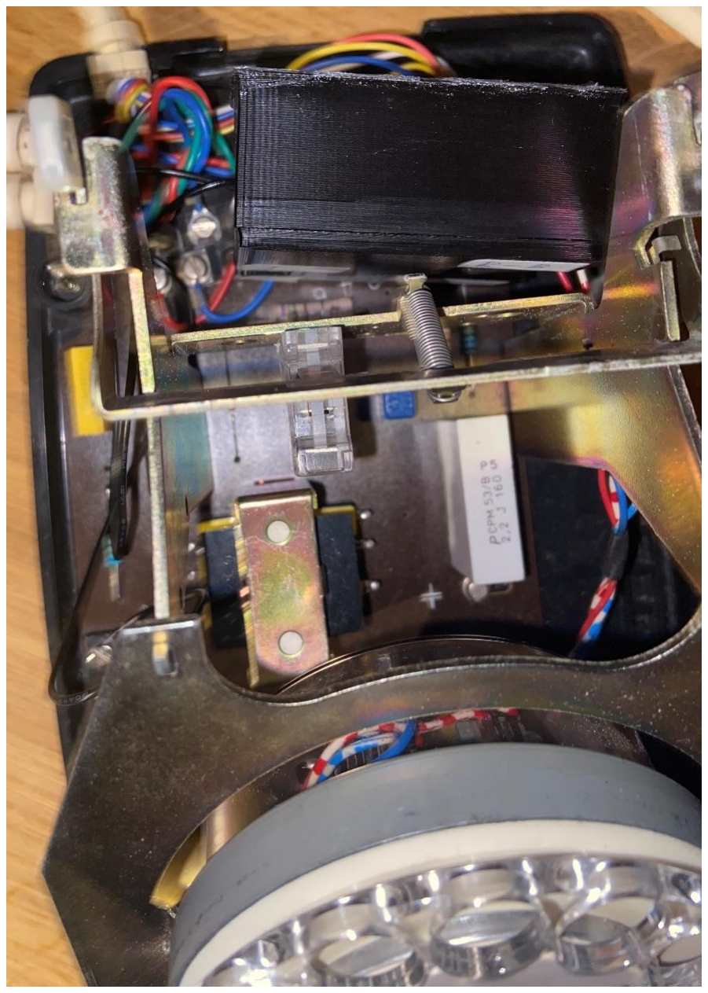
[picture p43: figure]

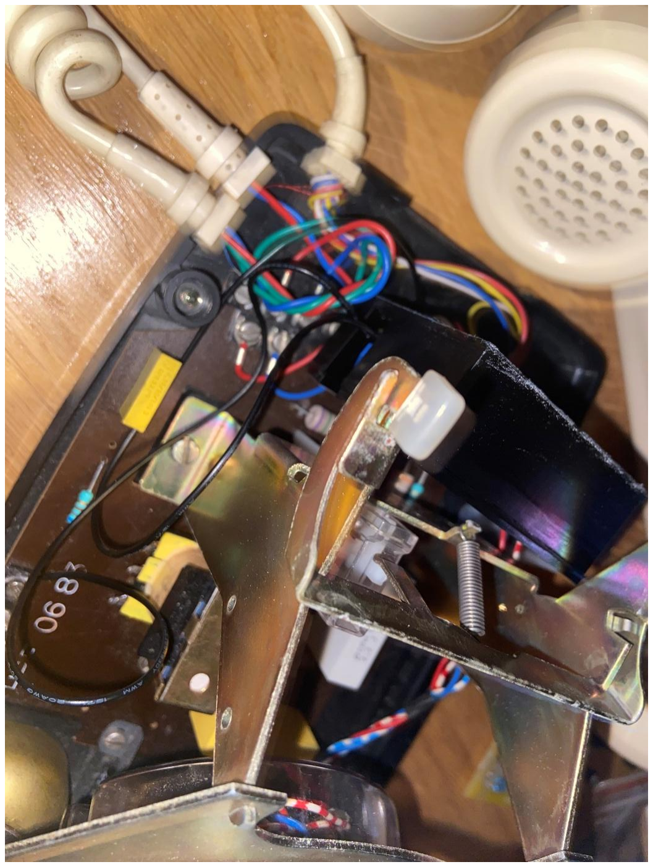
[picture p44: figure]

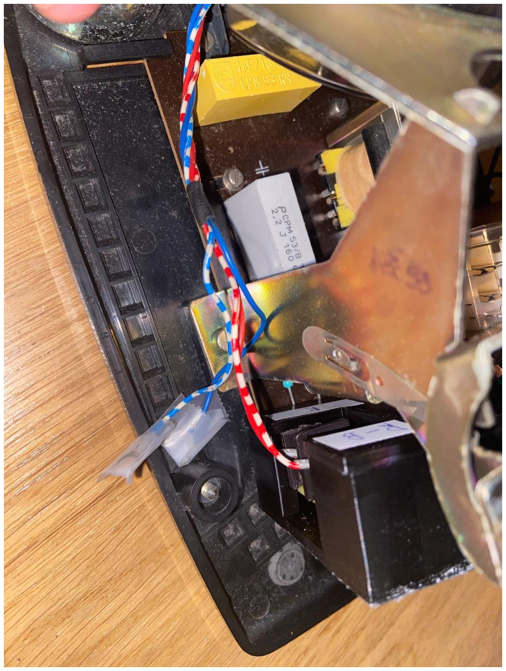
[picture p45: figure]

Quand vous refermez, vérifiez bien qu’aucun câble ne dépasse de la coque du téléphone et revissez bien les vis de ladite coque.

Et voilà ! Vous avez un téléphone capable d’appeler à nouveau !

# Liper

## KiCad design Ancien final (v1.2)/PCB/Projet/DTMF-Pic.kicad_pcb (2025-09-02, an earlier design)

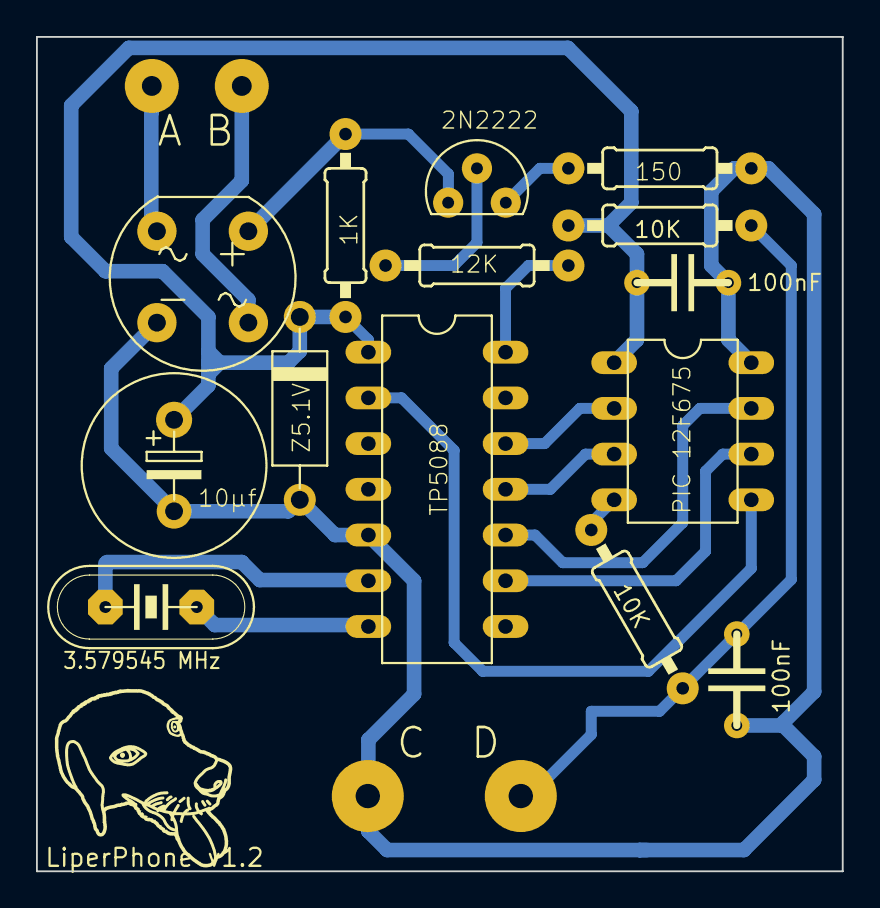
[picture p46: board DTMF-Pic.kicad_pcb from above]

Board: 2 copper layers, 44.8 x 46.4 mm, 14 parts (0 on the bottom side), 14 nets.

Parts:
E$1: DIL-8
E$2: DIL-14
E$3: PONT1A
E$4, E$5, E$6: RES-4
E$7, E$10: 10K; RES-4
E$8: DIO-4
E$9: QUARTZ
E$11: TO-92
E$12: 0.1F; CAP-2
E$13: CHIX2-4
E$14: 0.1µf; CAP-2

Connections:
S$1: E$2.7, E$9.1
S$4: E$7.1, E$10.1
S$5: E$2.6, E$9.2
S$6: E$1.1, E$2.1, E$4.1, E$8.2, E$10.2, E$12.P$1, E$13.1
S$7: E$6.2, E$11.2
S$8: E$1.2, E$2.12
S$9: E$1.5, E$2.2
S$10: E$2.14, E$6.1
S$11: E$1.3, E$2.11
S$12: E$1.7, E$2.10
S$13: E$1.6, E$2.9
S$15: E$1.4, E$7.2
S$16: E$3.1, E$4.2
S$18: E$1.8, E$2.5, E$3.4, E$5.1, E$8.1, E$12.P$2, E$13.2, E$14.P$1

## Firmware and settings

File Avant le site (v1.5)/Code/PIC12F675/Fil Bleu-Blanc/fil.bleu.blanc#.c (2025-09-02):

#include "pic12f675.h"
#include <xc.h>
#define _XTAL_FREQ 4000000UL

// ================== CONFIG ==================
#pragma config FOSC = INTRCIO  // Osc interne, GP4/GP5 en I/O
#pragma config WDTE = OFF
#pragma config PWRTE = OFF
#pragma config MCLRE = OFF
#pragma config BOREN = OFF
#pragma config CP = OFF
#pragma config CPD = OFF

// ================== CONSTANTES ==================
#define T_LONG_HOLD_MS       1000  // 1,5 s : appui long avant relâche
#define END_OF_TRAIN_MS       220  // fin de train d'impulsions
#define DEBOUNCE_MS             8  // anti-rebond
#define MIN_GAP_MS             25  // intervalle min entre fronts montants

// Nibbles TP5088 (D3..D0) d'après la table du datasheet
#define NIB_0  0b1010
#define NIB_1  0b0001
#define NIB_2  0b0010
#define NIB_3  0b0011
#define NIB_4  0b0100
#define NIB_5  0b0101
#define NIB_6  0b0110
#define NIB_7  0b0111
#define NIB_8  0b1000
#define NIB_9  0b1001
#define NIB_STAR 0b1011      // '*'
#define NIB_HASH 0b1100      // '#'

// ================== VARIABLES ==================
volatile unsigned long ms_tick = 0; // horloge libre (~1.024 ms / tick)
volatile unsigned long millis  = 0; // chrono réutilisé pour inter-impulsions

volatile unsigned char pulses = 0;     // nombre d'impulsions comptées
volatile unsigned char note   = 0;     // a-t-on reçu au moins une impulsion ?
volatile unsigned char last_pin = 0;   // mémorisation niveau GP3 (0/1)

volatile unsigned char state = 0;
#define ST_IDLE         0
#define ST_ARMED        1   // butée: bas maintenu avant 1er front montant
#define ST_COUNT        2   // train d'impulsions en cours
#define ST_WAIT_RELEASE 3   // on attend retour repos stable

// Mesures de temps (en ms_tick)
volatile unsigned long hold_start_ms = 0; // début palier bas (butée)
volatile unsigned long last_rise_ms  = 0; // dernier front montant
volatile unsigned char long_hold     = 0; // flag appui long détecté

// ================== PROTOTYPES ==================
void emit_dtmf_nibble(unsigned char nib, unsigned int on_ms);
void emit_digit_from_pulses(unsigned char p, unsigned char long_hold_flag);

// ================== ISR TMR0 -> 1 ms approx ==================
void __interrupt() ISR(void)
{
    if (INTCONbits.TMR0IE && INTCONbits.TMR0IF) {
        // TMR0 ~ 1.024 ms selon prescaler
        ms_tick++;
        millis++;
        INTCONbits.TMR0IF = 0;
    }
}

// ================== OUTILS TP5088 ==================
static inline void set_nibble(unsigned char nib) {
    // D3..D0 = GP5,GP4,GP0,GP1
    GPIObits.GP5 = (nib >> 3) & 1;
    GPIObits.GP4 = (nib >> 2) & 1;
    GPIObits.GP0 = (nib >> 1) & 1;
    GPIObits.GP1 = (nib >> 0) & 1;
}

void emit_dtmf_nibble(unsigned char nib, unsigned int on_ms)
{
    // Prépare les 4 bits
    set_nibble(nib);

    // Front montant sur TONE ENABLE pour "latcher" les données (datasheet)
    GPIObits.GP2 = 0;           // assure niveau bas
    __delay_us(10);
    GPIObits.GP2 = 1;           // latch + génération
    // Durée du tone
    while (on_ms--) __delay_ms(1);

    // Stoppe la génération
    GPIObits.GP2 = 0;
    // Remet les bits à 0 (propre)
    GPIObits.GP5 = 0;
    GPIObits.GP4 = 0;
    GPIObits.GP0 = 0;
    GPIObits.GP1 = 0;
}

void emit_digit_from_pulses(unsigned char p, unsigned char long_hold_flag)
{
    unsigned char nib;

    // 10 pulses = '0'
    if (p >= 10) p = 0;

    // Appui long: remapping spécial
    if (long_hold_flag) {
        if (p == 2) { nib = NIB_HASH; emit_dtmf_nibble(nib, 300); return; } // 2 ? '#'
        if (p == 1) { nib = NIB_STAR; emit_dtmf_nibble(nib, 300); return; } // 1 ? '*'
        // autres chiffres: comportement normal
    }

    switch (p) {
        case 0: nib = NIB_0; break;
        case 1: nib = NIB_1; break;
        case 2: nib = NIB_2; break;
        case 3: nib = NIB_3; break;
        case 4: nib = NIB_4; break;
        case 5: nib = NIB_5; break;
        case 6: nib = NIB_6; break;
        case 7: nib = NIB_7; break;
        case 8: nib = NIB_8; break;
        case 9: nib = NIB_9; break;
        default: nib = NIB_0; break; // sécurité
    }
    emit_dtmf_nibble(nib, 300);
}

// ================== MAIN ==================
void main(void)
{
    // ------- Init périphériques -------
    ANSEL = 0x00;      // tout en numérique
    CMCON = 0x07;      // désactive comparateurs
    TRISIO = 0b00001000;  // GP3 en entrée, le reste en sortie
    GPIO   = 0x00;

    // OPTION_REG:
    // b7=1 (pull-ups off), b6=0 (INTEDG), b5=0 (TMR0 clock=fosc/4),
    // b4=0 (T0SE), b3=0 (prescaler assigné à TMR0), b2..b0=001 (1:4)
    OPTION_REG = 0b10000001;

    // TMR0
    INTCONbits.TMR0IF = 0;
    INTCONbits.TMR0IE = 1;
    INTCONbits.GIE    = 1;

    // État initial entrée
    last_pin = GPIObits.GP3;     // repos attendu = 1 (5V)
    state = ST_IDLE;

    // ------- Boucle principale -------
    for(;;)
    {
        unsigned char pin = GPIObits.GP3;

        // ==== Détection fronts avec anti-rebond simple ====
        if (pin != last_pin) {
            // petit anti-rebond
            __delay_ms(DEBOUNCE_MS);
            pin = GPIObits.GP3;
        }

        // FRONT DESCENDANT : 5V -> 0V  : doigt sur butée
        if ((last_pin == 1) && (pin == 0)) {
            last_pin = 0;

            if (state == ST_IDLE) {
                state = ST_ARMED;
                hold_start_ms = ms_tick;   // début du palier bas
                long_hold = 0;
                pulses = 0;
                note = 0;
                // on laisse "millis" tel quel (il servira pour la fin de train)
            }
        }

        // FRONT MONTANT : 0V -> 5V  : début/continuité des impulsions
        if ((last_pin == 0) && (pin == 1)) {
            last_pin = 1;

            unsigned long now = ms_tick;

            if (state == ST_ARMED) {
                // 1er front montant => début du train
                unsigned long hold_ms = now - hold_start_ms;
                long_hold = (hold_ms >= T_LONG_HOLD_MS) ? 1 : 0;

                pulses = 1;
                note   = 1;
                millis = 0;                // chronomètre fin de train
                last_rise_ms = now;
                state  = ST_COUNT;
            }
            else if (state == ST_COUNT) {
                // Fronts montants suivants (compter en filtrant les rebonds)
                if ((now - last_rise_ms) >= MIN_GAP_MS) {
                    pulses++;
                    last_rise_ms = now;
                    millis = 0;            // reset fin de train
                }
            }
        }

        // ==== Fin de train : plus de fronts depuis un moment ====
        if ((state == ST_COUNT) && (note == 1) && (millis > END_OF_TRAIN_MS)) {
            // Train terminé : convertir et émettre
            emit_digit_from_pulses(pulses, long_hold);

            // Remise à zéro pour le prochain chiffre
            pulses = 0;
            note   = 0;
            long_hold = 0;
            state  = ST_WAIT_RELEASE;
        }

        // ==== Retour repos: s'assurer que le cadran est bien relâché ====
        if ((state == ST_WAIT_RELEASE) && (pin == 1)) {
            // pin=1 (5V) maintenu -> on peut repartir
            state = ST_IDLE;
        }
    }
}

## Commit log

2025-02-03 ajout du fichiers source du PCB ainsi que du Gerber
    [DTMF-Pic.brd]
2025-02-03 Déplacement du fichier source
    [DTMF-Pic.brd]
2025-02-03 Suppression de tr
2025-09-02 Transfer de deux ancien dossier dans Ancien pas ouf
    [DTMF-Pic.brd]
2025-09-02 Rajout de truc mdr dossier et tout
2025-09-02 Plein de truc
    [Aelig 1 (3).SLDPRT, Aelig 1 1mm.STL, Aelig 2 (1).SLDPRT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]
2026-07-03 Ajout dernière version.
    [Bas LiperPhone v1.5.SLDPRT, Bas LiperPhone v1.5.STL, Bas LiperPhone v1.6.SLDPRT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]
